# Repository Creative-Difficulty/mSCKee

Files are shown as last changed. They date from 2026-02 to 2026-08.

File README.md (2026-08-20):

# mSCKee



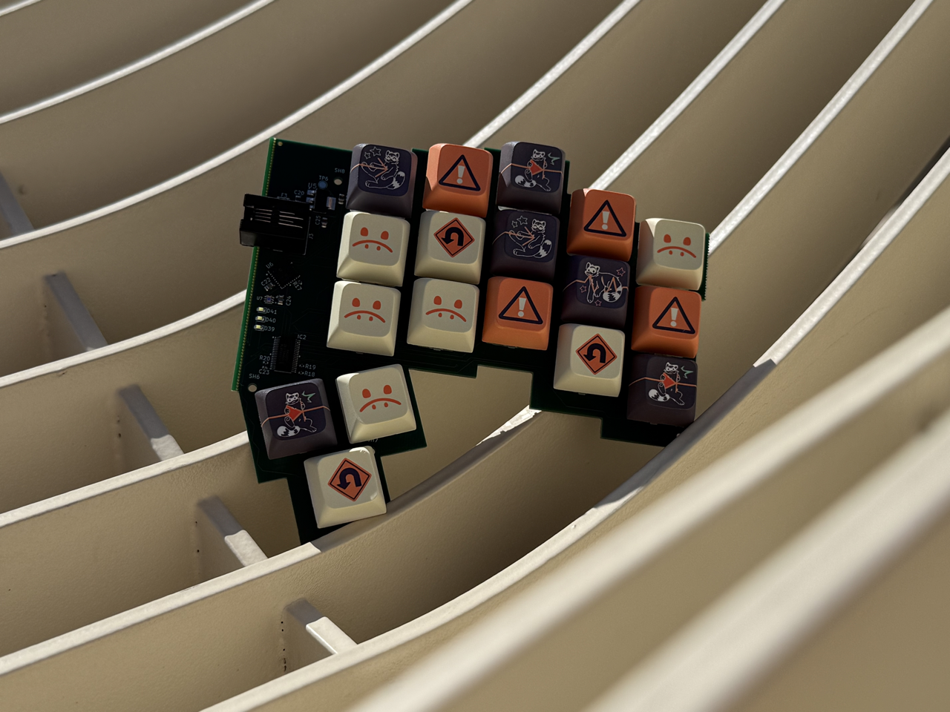
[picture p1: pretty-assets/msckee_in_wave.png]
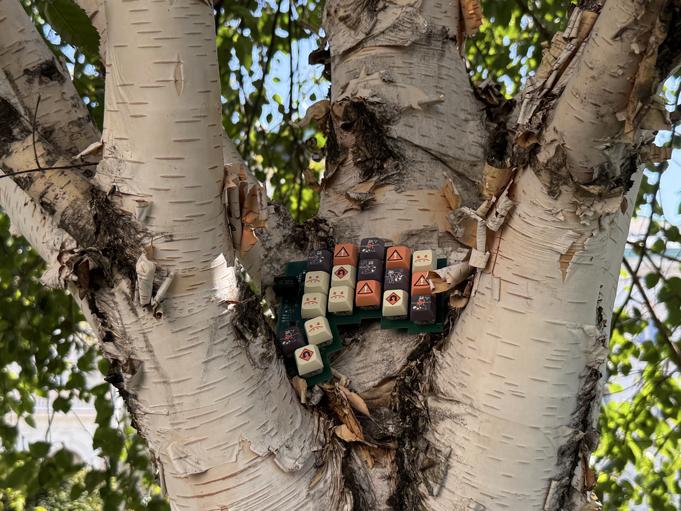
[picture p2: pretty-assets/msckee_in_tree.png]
| | |
|-|-|

__msCKee__ is an open source split Keyboard with per-key white backlighting, and two light sensors, adapting to ambient brightness.

It features:
- dimmable white backlighting for every key, programmable to display animations
- two light sensors (one per side) to automatically dim backlight
- Integrated RP2040 MCU IC
- Minimalist aluminium enclosure
- USB-C 2.0 connectivity
- 4 layer board: Signal - GND - 3,3V and 5V split pour - Signal
- RJ9 cable connection between halves
- Cherry MX 5 pin switch compatible

All manufacturing and part costs were covered by Hack Club through their Outpost program (<https://outpost.hackclub.com>), which I am very grateful for.

Keycaps are custom from Hack Club for Outpost, product photos (top of the README) were taken in Vienna, Austria.

## BOM

The JLC BOM covers the majority of expenses:
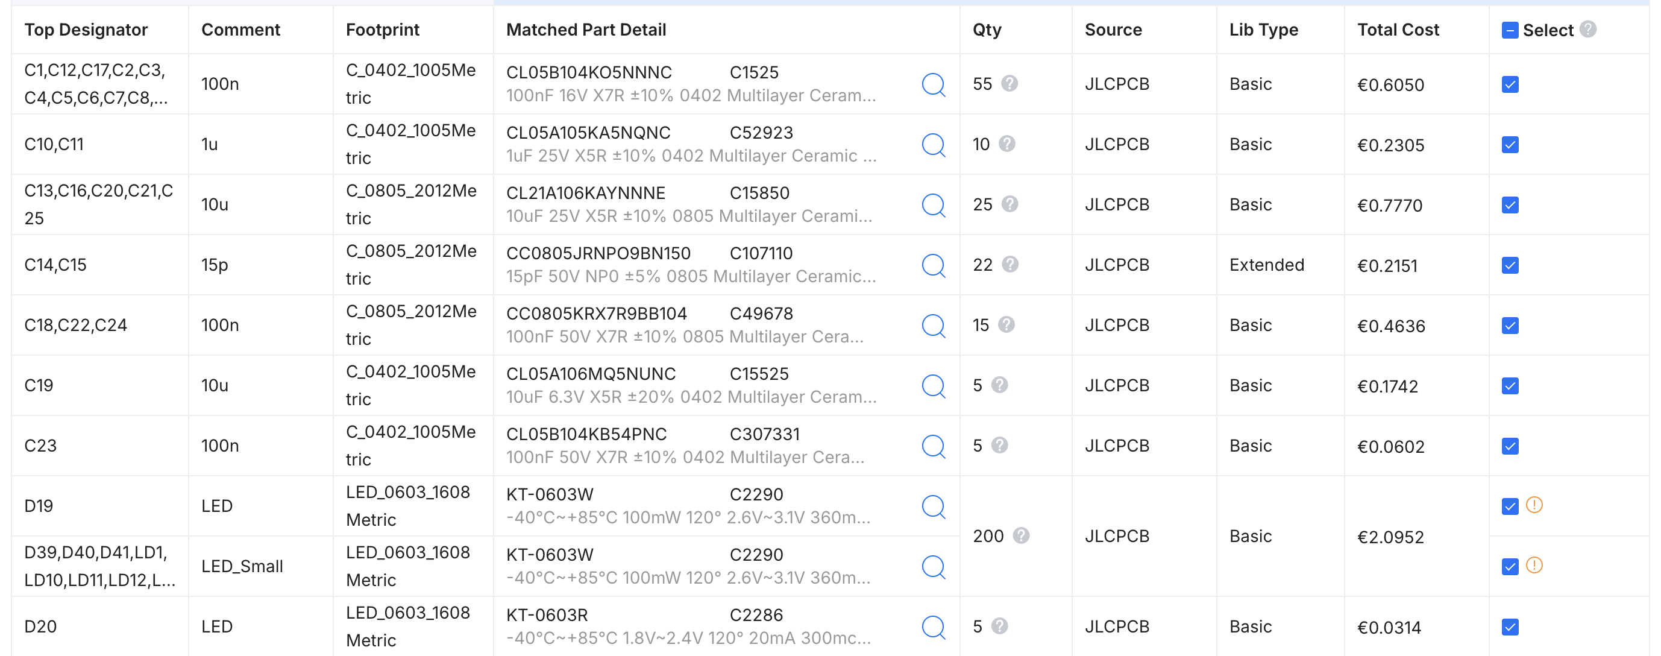
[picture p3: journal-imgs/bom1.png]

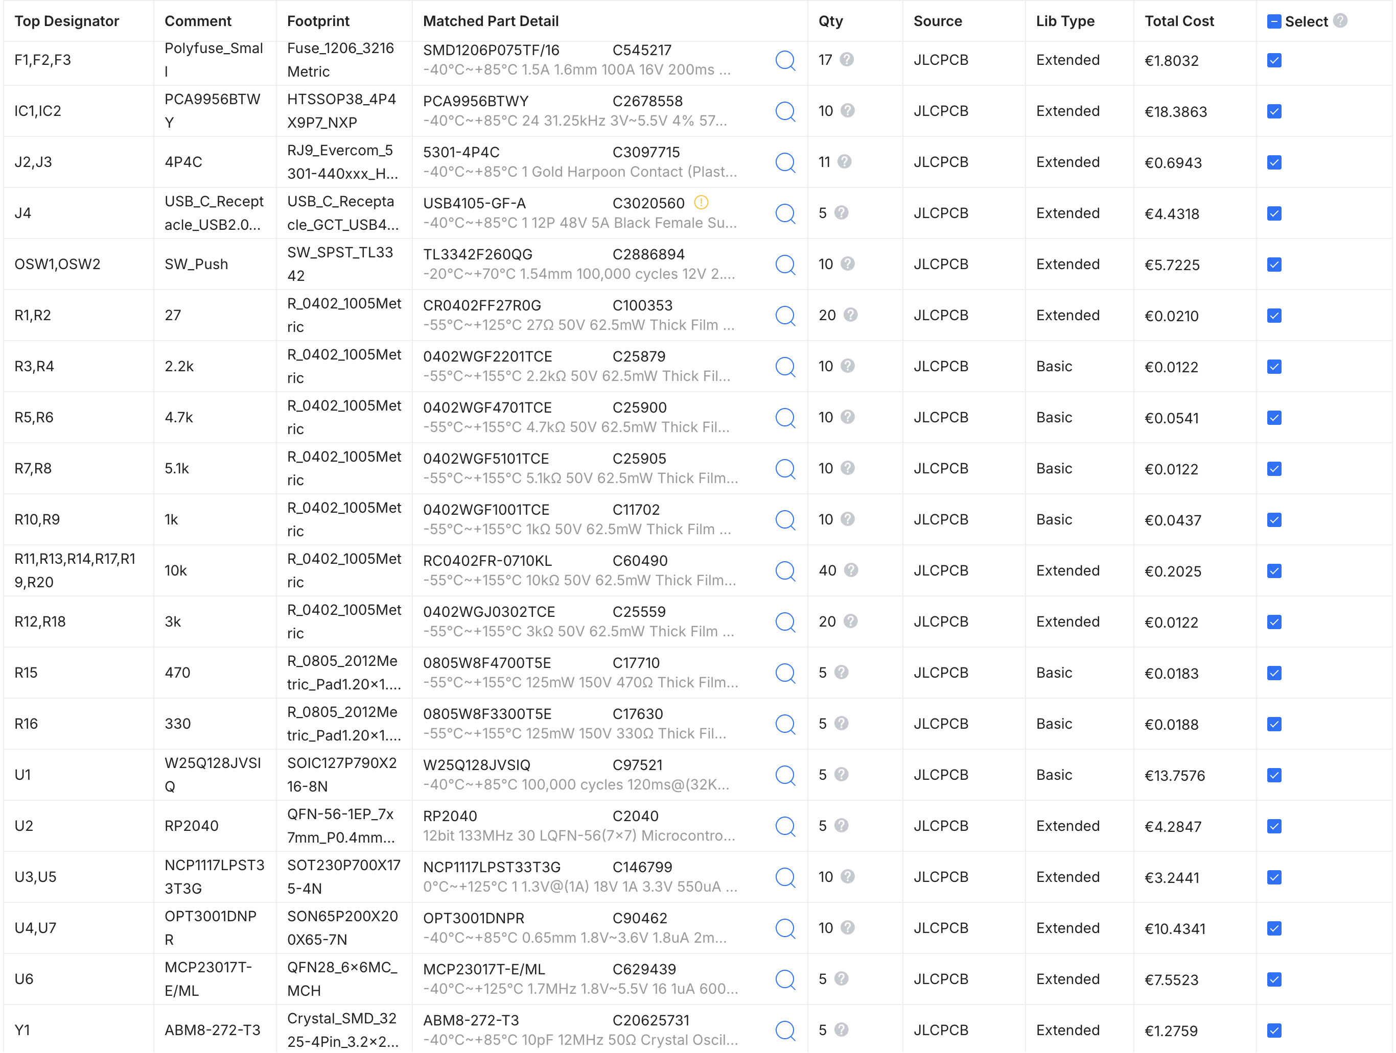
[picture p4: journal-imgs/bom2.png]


Total cost of JLCPCB(A):
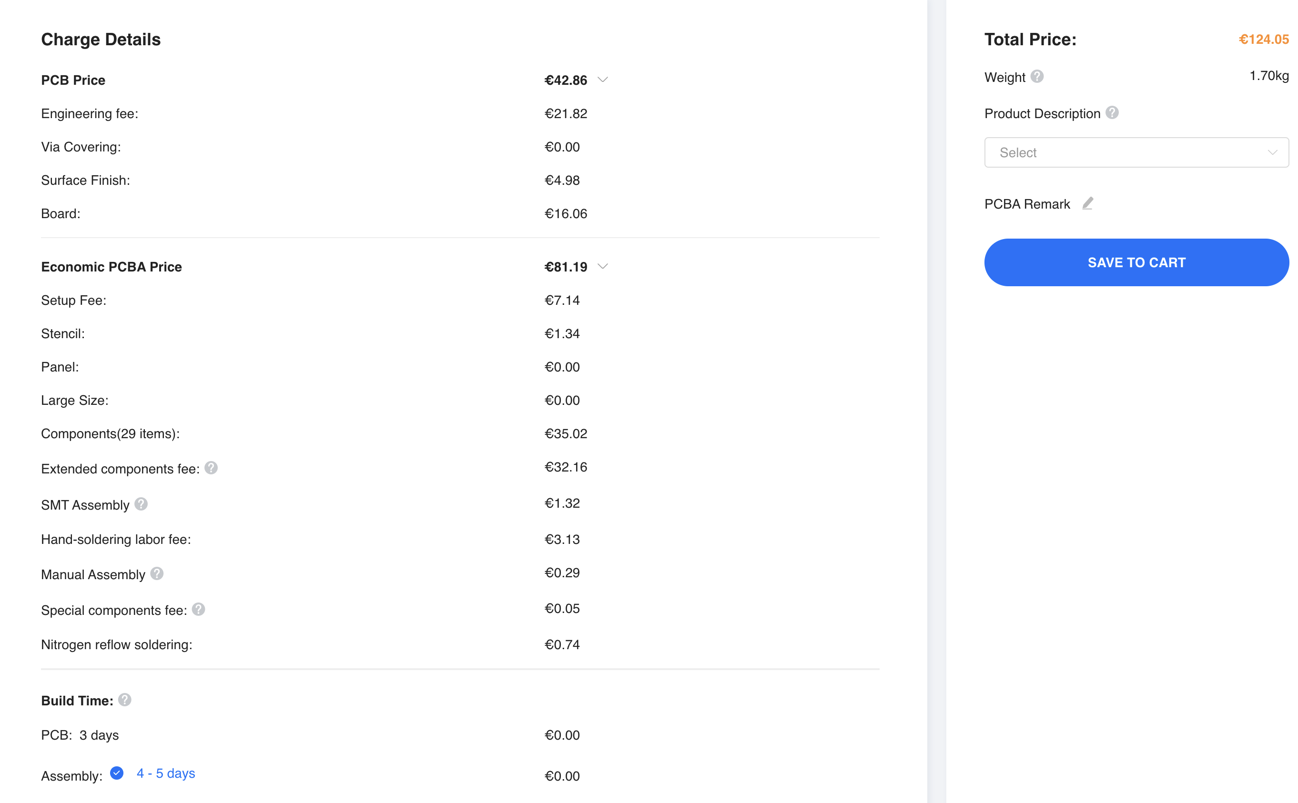
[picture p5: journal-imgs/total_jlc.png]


| Description | Price/Piece | Total Price | Purchase link | Justification |
|---|---|---|---|---|
| JLCPCB manufacturing and PCB assembly | 124.05€ + 22.72€ shipping | 146.77€ | | |
| Cherry MX Red Switch kit | 17.99€ + 11.99€ shipping | 29.98€ | https://shop.cherry.de/cherry-mx2a-rgb-red-switch-kit.html | |
| SP3T Switch: PCM13SMTR | 0.82€ | 5×0.82€ + 5.90€ shipping + 20% VAT = 12€ | https://www.tme.eu/at/details/pcm13smtr/schiebeschalter/c-k/ | No equivalent SP3T switch is available at JLC |
| 1N4148W7F DII SOD-123 diode | 0.05€ | 36×0.05€ + 6.95€ shipping + 20% VAT = 10.5€ | https://www.reichelt.com/at/en/shop/product/small-signal_switching_diode_100_v_300_ma_sod-123-219381 | Diodes for key matrix, mounted on back side of PCB, so not assembled or provided by JLC |
| **Total** | | **199.25€** | | |
| **Total (USD)** | | **232.59USD** | | |

## PCB & schematic images
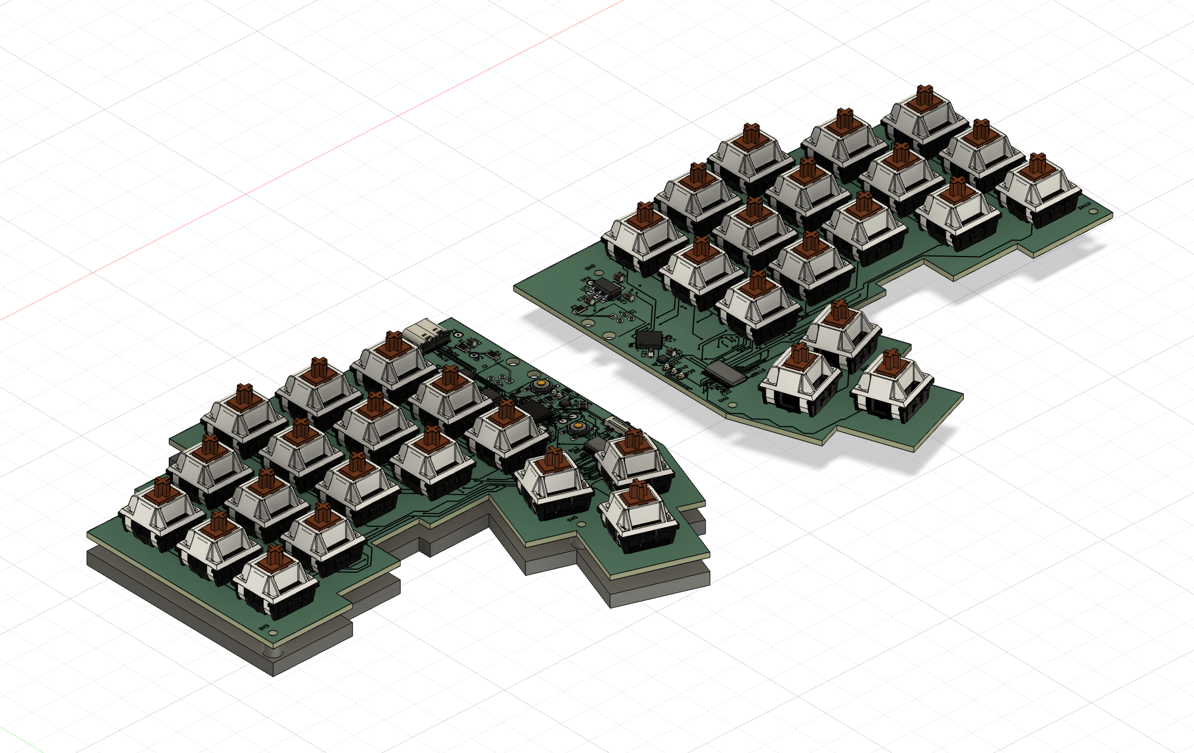
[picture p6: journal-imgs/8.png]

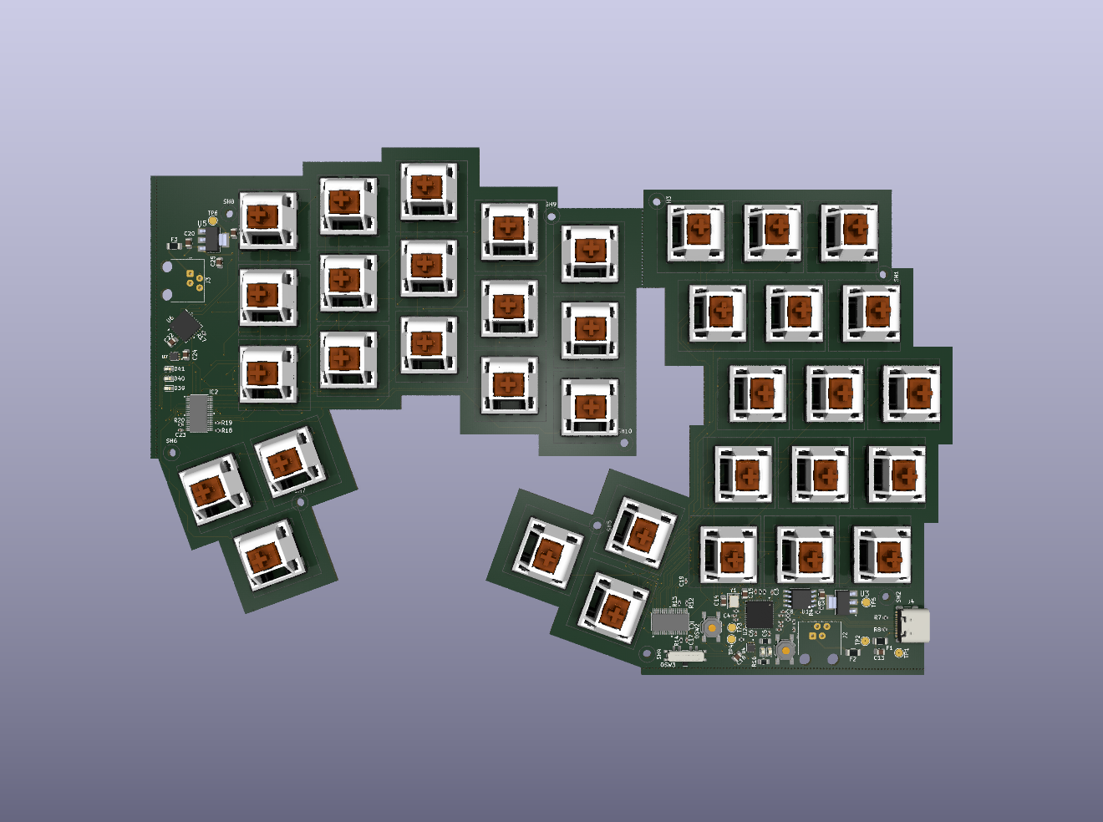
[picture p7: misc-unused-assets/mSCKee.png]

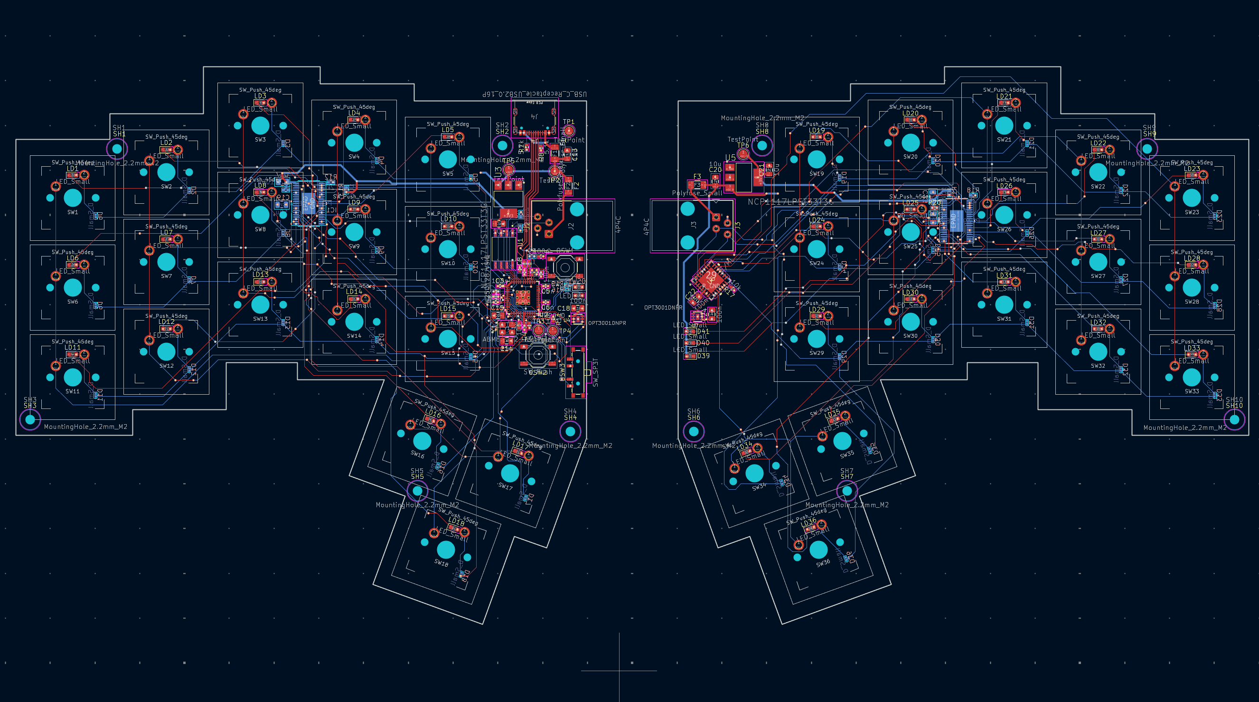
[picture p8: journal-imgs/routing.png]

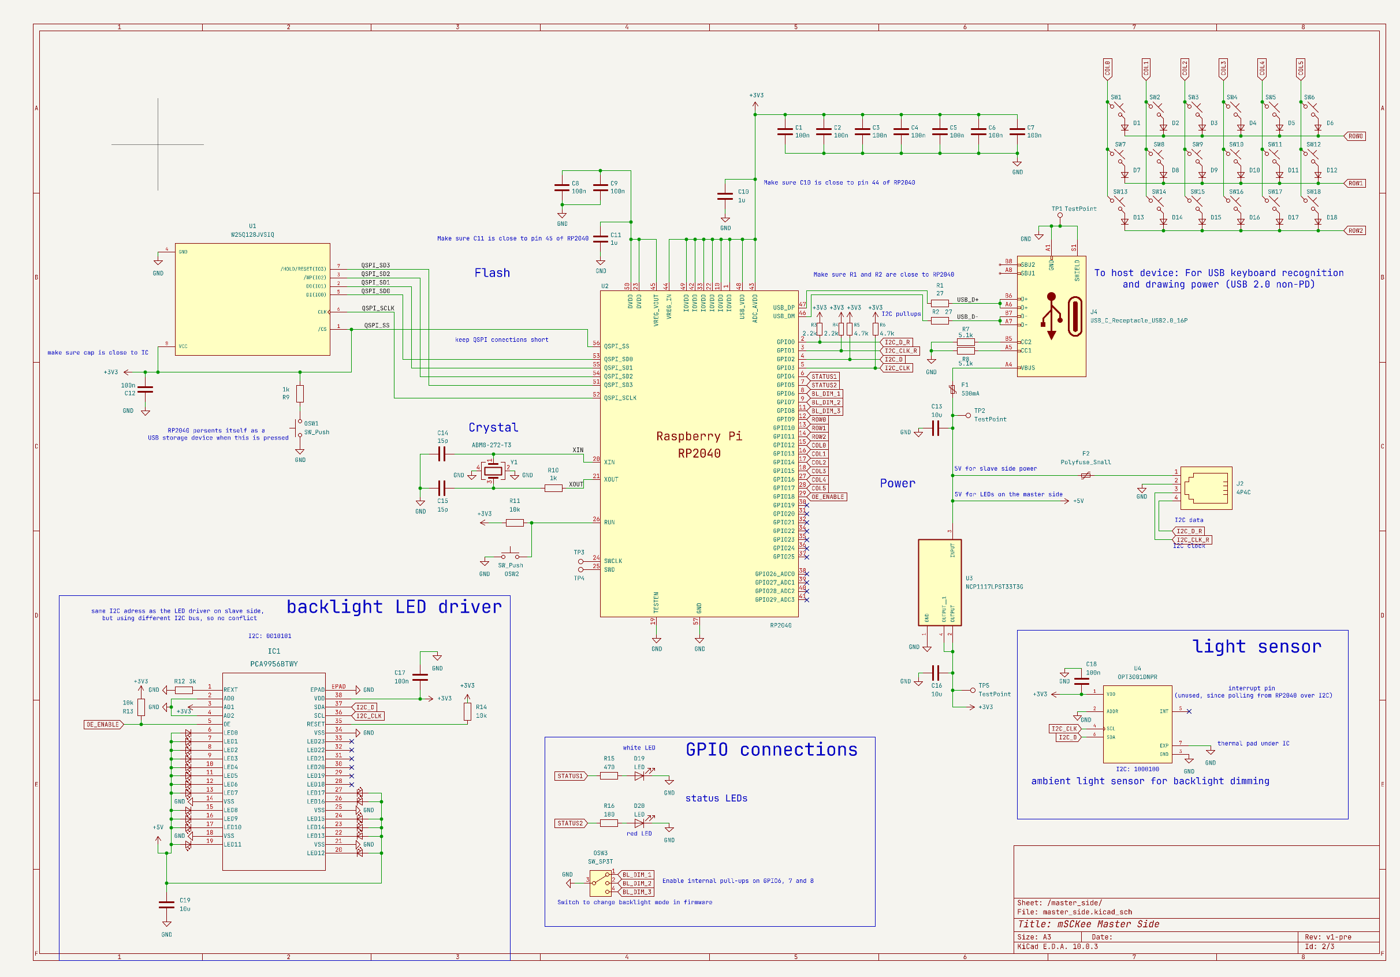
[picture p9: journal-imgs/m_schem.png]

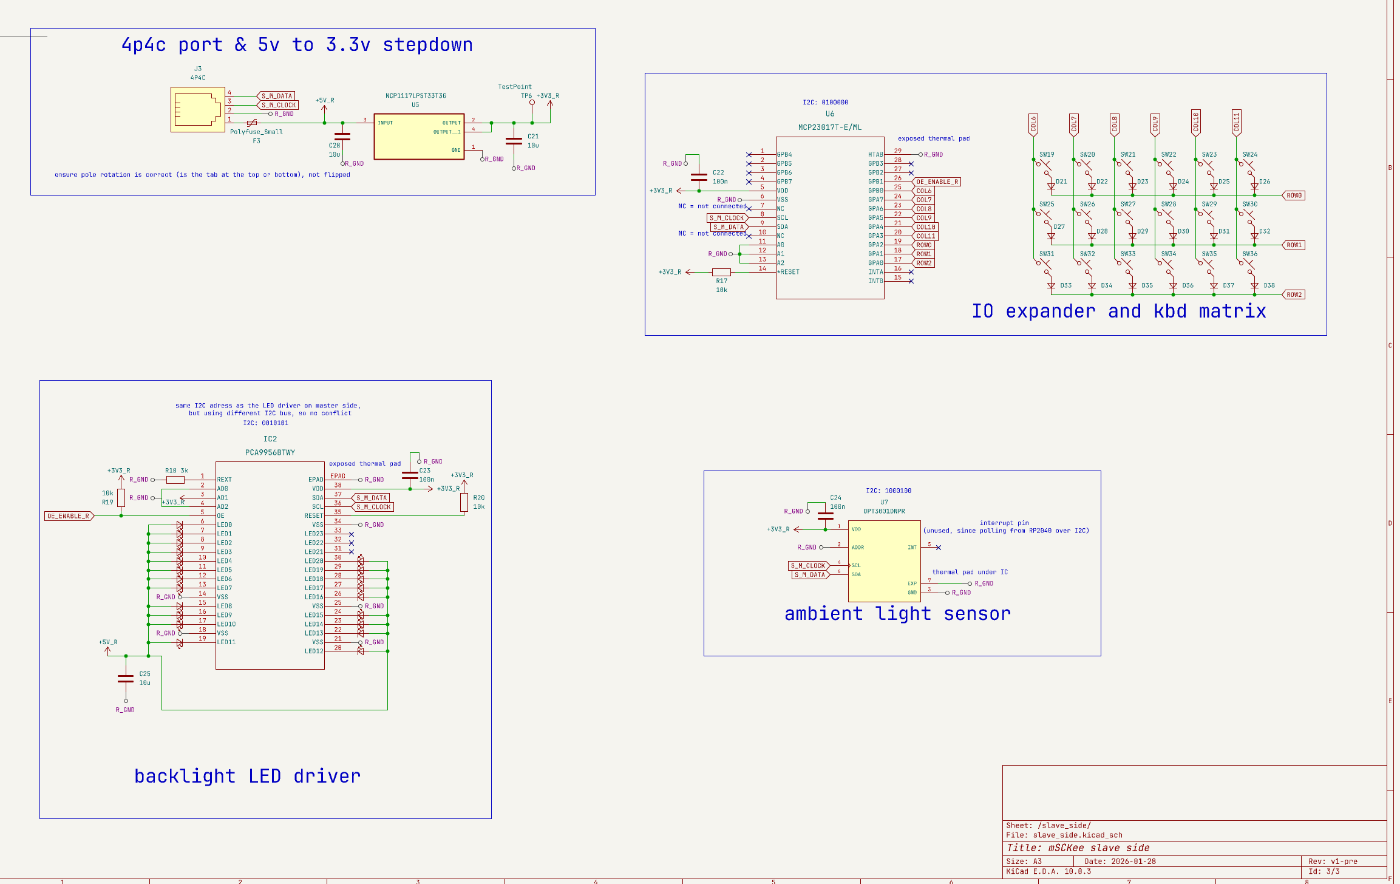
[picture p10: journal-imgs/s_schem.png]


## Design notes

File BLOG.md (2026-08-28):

The PCB arrived, and it worked perfectly, except - It didn't. The RP2040 booted up perfectly but as soon as I tried to flash a test firmware, the board (used as a storage device) ejected itself from Finder. 
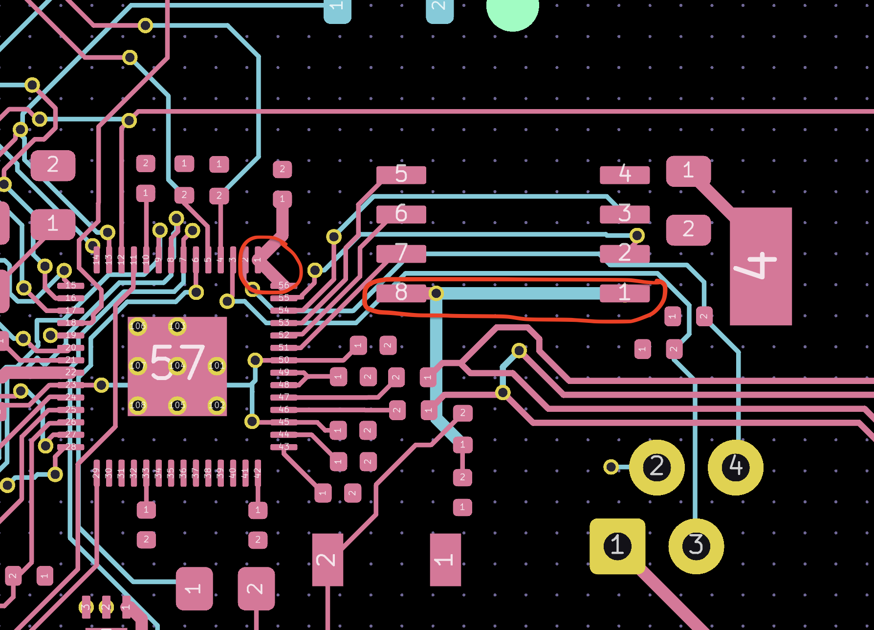
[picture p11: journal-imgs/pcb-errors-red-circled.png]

After some continuity testing with a multimeter, I discovered that I had connected the QSPI CS (chip select) pin of the RP2040 (Pin 56) to the IOVDD pin (Pin 1, a 3,3V input pin powering the RP2040's GPIO pins) and the CS pin (Pin 1) of the WS25Q128 storage chip to the 3,3V net by connecting it to pin 8 of the same chip, which was tied to 3,3V.
This made the storage chip unusable as the chip select pin doesn't ever select or deselect the chip.
KiCad's ratsnet previously led me to believe I had to connect these two (by displaying "+3V3" on them), and while I rembered this quirk when beginning to layout and route the board, a couple weeks later, by the time I ordered the board, I forgot it, and didn't double check with the datasheet one last time.

Due to me not having a hot air station at home, I went to a hackspace in Vienna ([Metalab](https://metalab.at/) in the first district, you should check it out!!) to try and fix the board.

First I desoldered the RP2040:
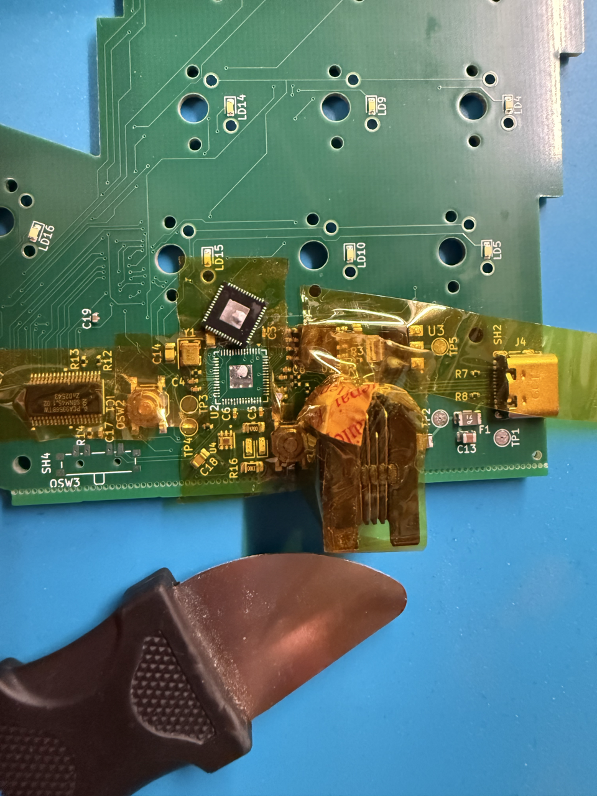
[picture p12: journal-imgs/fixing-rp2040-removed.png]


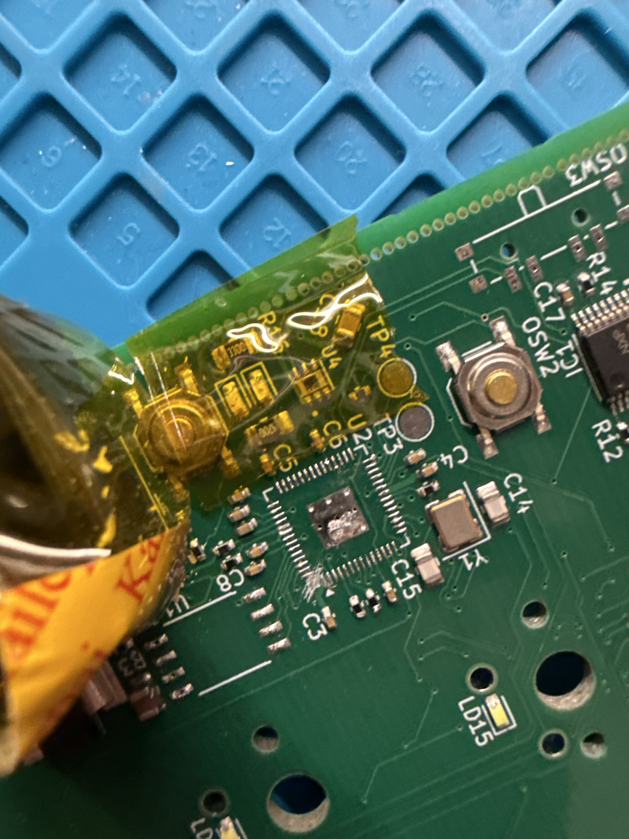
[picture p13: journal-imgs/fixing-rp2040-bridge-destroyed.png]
And broke the connection between pin 56 and pin 1 by scratching it up with a knife: 

I also broke the connection between the storage chip's pin 1 and pin 8 to isolate that pin.

As I've never used a hot air station before, I may have broken the RP2040 and/or W25Q128 storage chip by using too much heat for too long.

I don't have solder paste, flux or a stencil for the RP2040, and I am not confident that I am able to resolder it correctly (RP2040 has a pin pitch of 0.4mm).

While desoldering the storage chip, I unfortunately broke off one of its leads, so I'll have to find a replacement for it.

The best option I know of is reordering the board, which costs 207$. If I manage to resolder the RP2040, I can likely do the repair for a lot cheaper.
I have a second untouched assembled PCB from JLC, and I will try to fix that before reordering.

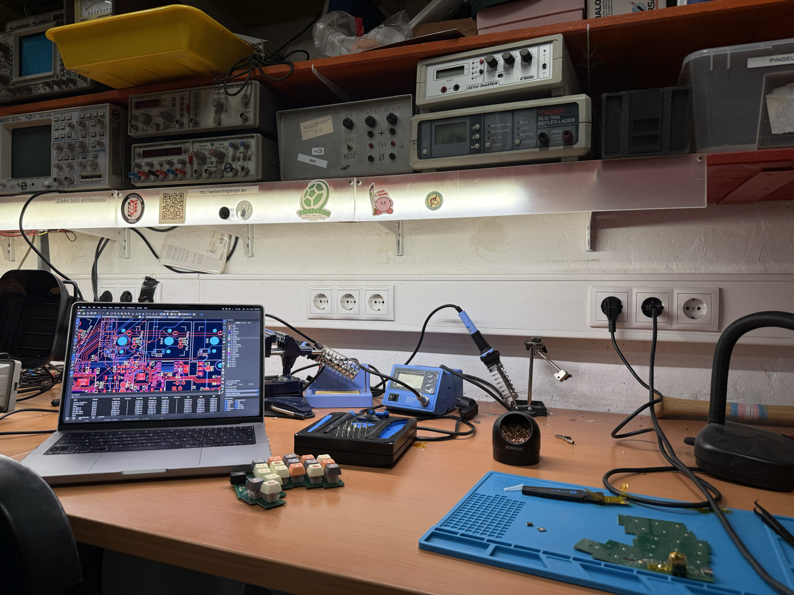
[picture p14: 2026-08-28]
journal-imgs/fixing-overview.png

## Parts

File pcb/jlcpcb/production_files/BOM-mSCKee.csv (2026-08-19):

Comment | Designator | Footprint | LCSC | Quantity
100n | C1,C12,C17,C2,C3,C4,C5,C6,C7,C8,C9 | C_0402_1005Metric | C1525 | 11
100n | C23 | C_0402_1005Metric | C307331 | 1
100n | C18,C22,C24 | C_0805_2012Metric | C49678 | 3
10k | R11,R13,R14,R17,R19,R20 | R_0402_1005Metric | C60490 | 6
10u | C19 | C_0402_1005Metric | C15525 | 1
10u | C13,C16,C20,C21,C25 | C_0805_2012Metric | C15850 | 5
15p | C14,C15 | C_0805_2012Metric | C107110 | 2
1k | R10,R9 | R_0402_1005Metric | C11702 | 2
1u | C10,C11 | C_0402_1005Metric | C52923 | 2
2.2k | R3,R4 | R_0402_1005Metric | C25879 | 2
27 | R1,R2 | R_0402_1005Metric | C100353 | 2
330 | R16 | R_0805_2012Metric_Pad1.20x1.40mm_HandSolder | C17630 | 1
3k | R12,R18 | R_0402_1005Metric | C100635 | 2
4.7k | R5,R6 | R_0402_1005Metric | C105871 | 2
470 | R15 | R_0805_2012Metric_Pad1.20x1.40mm_HandSolder | C17710 | 1
4P4C | J2,J3 | RJ9_Evercom_5301-440xxx_Horizontal | C3097715 | 2
5.1k | R7,R8 | R_0402_1005Metric | C25905 | 2
ABM8-272-T3 | Y1 | Crystal_SMD_3225-4Pin_3.2x2.5mm | C20625731 | 1
D_Small | D1,D10,D11,D12,D13,D14,D15,D16,D17,D18,D2,D21,D22,D23,D24,D25,D26,D27,D28,D29,D3,D30,D31,D32,D33,D34,D35,D36,D37,D38,D4,D5,D6,D7,D8,D9 | D_SOD-123 | C81598 | 36
LED | D20 | LED_0603_1608Metric | C2286 | 1
LED | D19 | LED_0603_1608Metric | C2290 | 1
LED_Small | D39,D40,D41,LD1,LD10,LD11,LD12,LD13,LD14,LD15,LD16,LD17,LD18,LD19,LD2,LD20,LD21,LD22,LD23,LD24,LD25,LD26,LD27,LD28,LD29,LD3,LD30,LD31,LD32,LD33,LD34,LD35,LD36,LD4,LD5,LD6,LD7,LD8,LD9 | LED_0603_1608Metric | C2290 | 39
MCP23017T-E/ML | U6 | QFN28_6x6MC_MCH | C629439 | 1
NCP1117LPST33T3G | U3,U5 | SOT230P700X175-4N | C146799 | 2
OPT3001DNPR | U4,U7 | SON65P200X200X65-7N | C90462 | 2
PCA9956BTWY | IC1,IC2 | HTSSOP38_4P4X9P7_NXP | C2678558 | 2
Polyfuse_Small | F1,F2,F3 | Fuse_1206_3216Metric | C545217 | 3
RP2040 | U2 | QFN-56-1EP_7x7mm_P0.4mm_EP3.2x3.2mm | C2040 | 1
SW_Push | OSW1,OSW2 | SW_SPST_TL3342 | C2886898 | 2
USB_C_Receptacle_USB2.0_16P | J4 | USB_C_Receptacle_GCT_USB4105-xx-A_16P_TopMnt_Horizontal | C3020560 | 1
W25Q128JVSIQ | U1 | SOIC127P790X216-8N | C97521 | 1
TestPoint | TP5 | TestPoint_Pad_D2.0mm |  | 1
TestPoint | TP4 | TestPoint_Pad_D2.0mm |  | 1
TestPoint | TP3 | TestPoint_Pad_D2.0mm |  | 1
TestPoint | TP1 | TestPoint_Pad_D2.0mm |  | 1
TestPoint | TP2 | TestPoint_Pad_D2.0mm |  | 1
TestPoint | TP6 | TestPoint_Pad_D2.0mm |  | 1

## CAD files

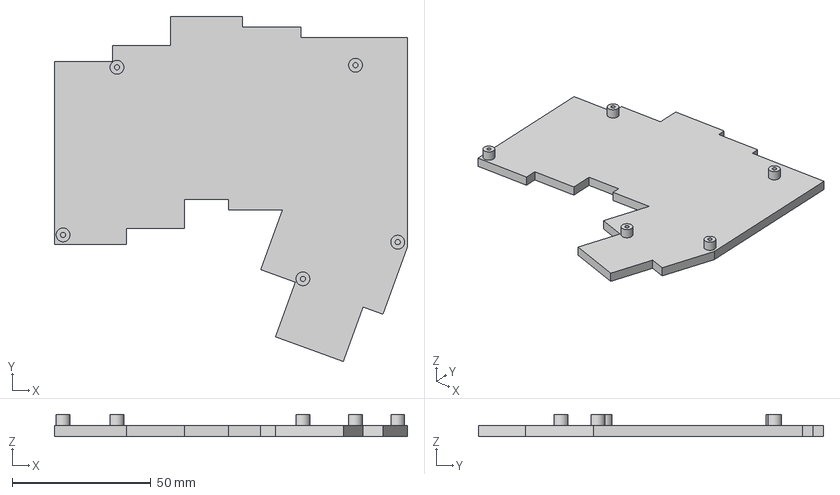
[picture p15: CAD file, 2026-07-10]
cad/minimal Case.step
127.5 x 124.4 x 8.00 mm

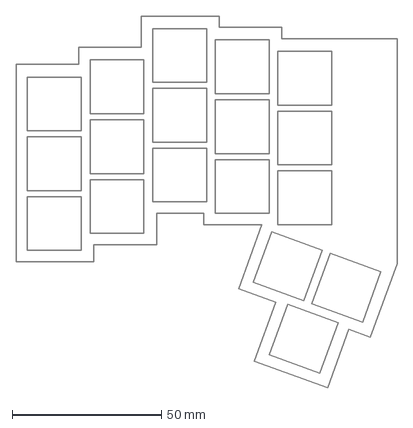
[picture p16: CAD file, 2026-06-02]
outline_and_keys.dxf
127.5 x 124.4 mm

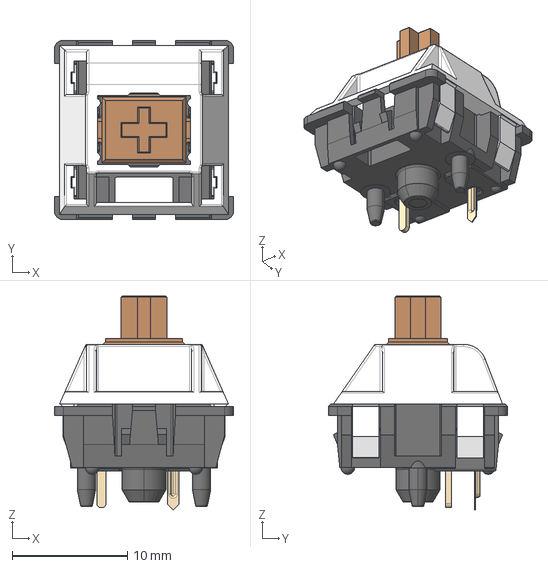
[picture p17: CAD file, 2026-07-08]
pcb/pcb-lib/ai03-MX_V2/kiswitch-SW_Cherry_MX_PCB.stp
15.6 x 15.6 x 18.6 mm

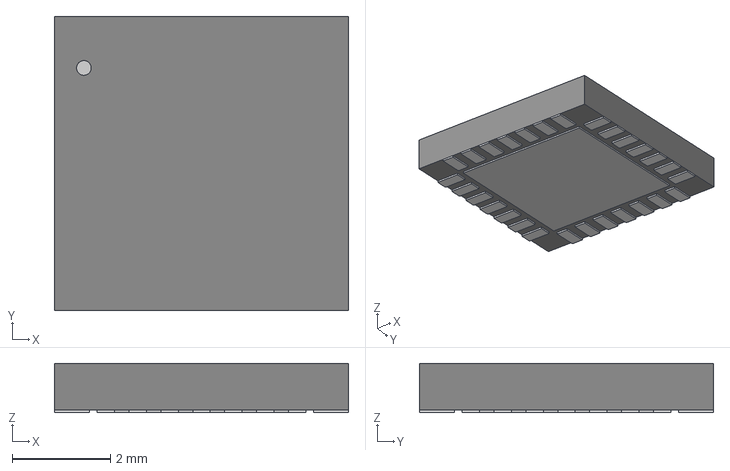
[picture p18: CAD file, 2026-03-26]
pcb/pcb-lib/MCP23017T_E_ML/QFN28_6x6MC_MCH.step
6.00 x 6.00 x 1.00 mm

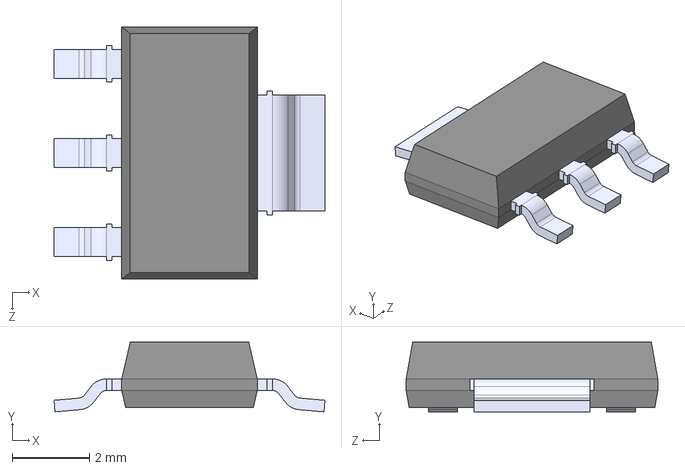
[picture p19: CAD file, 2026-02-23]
pcb/pcb-lib/NCP1117LPST33T3G/NCP1117LPST33T3G.step
7.00 x 1.80 x 6.50 mm

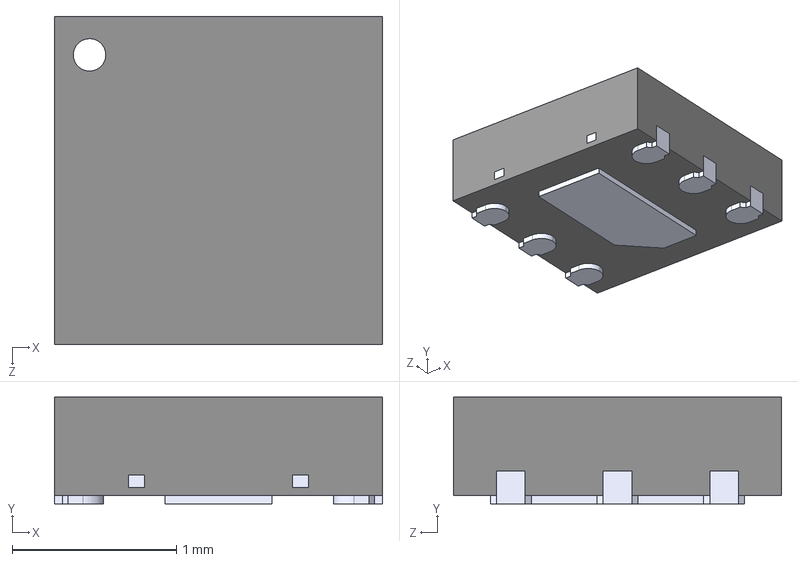
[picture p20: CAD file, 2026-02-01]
pcb/pcb-lib/OPT3001DNPR/OPT3001DNPR.step
2.00 x 0.65 x 2.00 mm

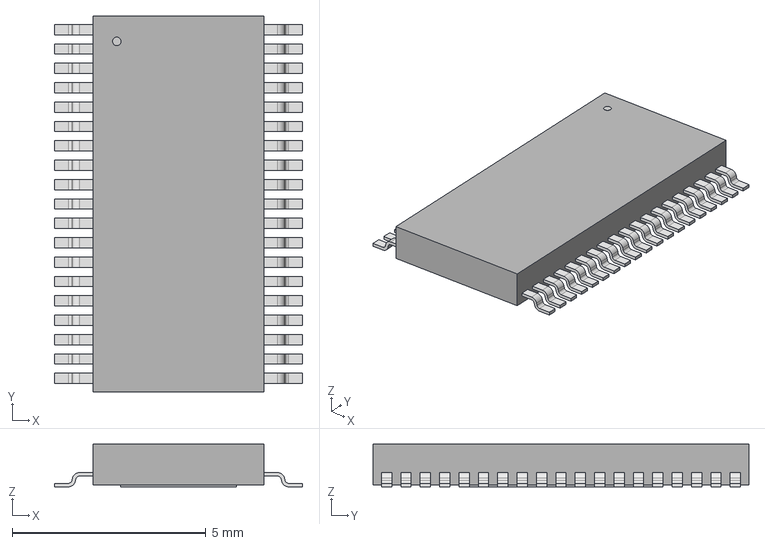
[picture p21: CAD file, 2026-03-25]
pcb/pcb-lib/PCA9956BTWY/HTSSOP38_4P4X9P7_NXP.step
6.40 x 9.70 x 1.10 mm

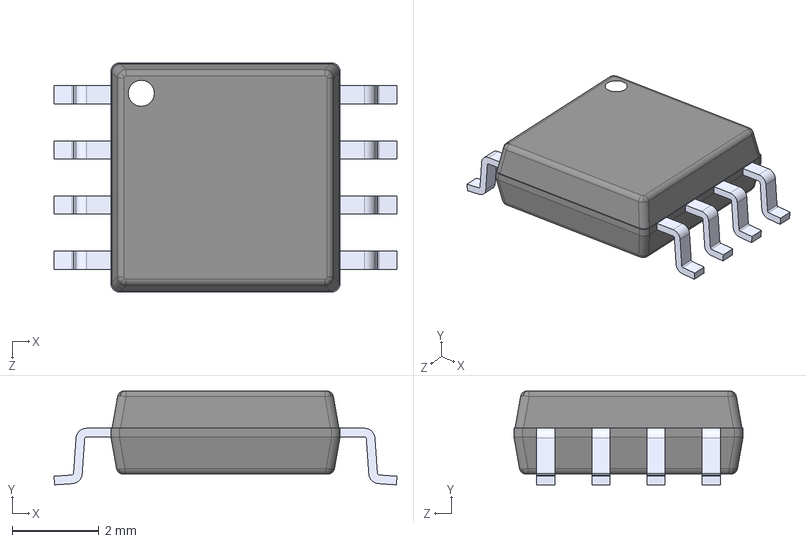
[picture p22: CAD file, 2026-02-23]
pcb/pcb-lib/W25Q128JVSIQ/W25Q128JVSIQ.step
7.90 x 2.16 x 5.28 mm

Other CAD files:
misc-unused-assets/minimal Case.step
Outline and keys.dxf
cad/minimal Case.f3z
misc-unused-assets/minimal Case.f3z

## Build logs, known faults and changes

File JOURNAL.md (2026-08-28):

# Split Keyboard with per-key backlighting — Journal 

## Entry 1: 1 hour

- ID: 16105
- Author: Alex
- Created At: 2025-10-31T22:29:00Z

### Content

My first journal entry for my first hardware project :)

# Rough Scope / Requirements

The first iteration of the keyboard will only be a modification of the one in the guide, as I'm still a beginner at KiCad, electronics and PCB design. These are the main differences between this board and the guide:

- RP2040 instead of nRF microcontroller
- Neopixels or similar LEDs under every key
- Only one chip will be used for both sides (master slave concept)
- Connectivity: Just USB-C, so no battery will be used
- In future iterations: The ability to attach a variety of (magnetic?) modules to the side of the keyboard  with:
  - Rotary encoders (e.g. volume dial)
  - push buttons (e.g. hotswappable additional keys, but also normal buttons)
  - toggle switches (could be used for simracing or flight simmming)
  - etc (to be determined)

# Component selection

- Main (Master) Microcontroller: likely RP2040
- Slave: I2C expander or parallel-in shift register which sends data to Master
- For data transmission between master (left side) and slave (right side): Likely TRRS if the bandwidth is sufficient

# First concept design

Bildschirmfoto 2025-10-31 um 23.16.49

## Entry 2: 15 hours

- ID: 16106
- Author: Alex
- Created At: 2026-01-31T14:52:00Z

### Content

Since the last journal, I've spent a bunch of time researching, learning electronics fundamentals and redesigning the basic RP2040 circuit (USB-C, flash, clock) over and over again.

I spent 5 hours researching electronics, component selections, PCB design and routing. Great Scott on youtube does a great (hehe) job of explaining the fundamental components, for higher level (concepts like I2C and SPI), Altium Academy has some great videos. I also read through The RP2040 hardware design guide (<https://pip-assets.raspberrypi.com/categories/814-rp2040/documents/RP-008279-DS-1-hardware-design-with-rp2040.pdf>) and used it as a reference in addition to the RP2040 datasheet.

After getting a grasp on the basics, I started designing the circuit schema in KiCad, starting with the left side of the split. I took the recommended minimal RP2040 circuit from the hardware design guide, then I replaced microUSB with a type C connector (more modern, better compatibility) and messed around with the layout of the traces connecting the MCU to the flash until I found a better layout (the flash reset button wiring in the hardware design guide is very confusing in my opinion). I also landed on splitting off a power rail to the other side of the keyboard (just branching out a trace before the buck converter (ncp1117) and feeding it directly into a TRRS receptacle), after spending about half an hour researching and realizing there is no better solution. In total this also took about 5 hours.

The power-related stuff on the left side of the split:
Bildschirmfoto 2026-06-01 um 00.57.57

Then I added status LEDs, the TRRS receptacle to connect the two halves, an ambient light sensor for automatic backlight dimming (TI OPT3001), a rotary encoder as a volume knob, and a button to switch between backlight dimming modes. I used the datasheets of the components as a reference (ctrl+f was my best friend). Initially, I was drawn to using a switch for selecting backlighting modes, however after descending into the madness that are different types of switches and wiring, I decided to opt for the simpler solution of just using a push button. This took about 5 hours in total since I wasn't familiar with the components (especially the light sensor).

GPIO connections on the left side (TRRS not pictured here, but on above screenshot with other power-related components):
Bildschirmfoto 2026-06-01 um 01.01.15

Next things to do are: keyboard matrix, backlighting, and figuring out how to avoid shorting the various poles of the TRRS cable together when plugging/unplugging it while powered.

Current screenshot of the entire schematic for the "master" side (left):
Bildschirmfoto 2026-01-31 um 15.36.46

## Entry 3: 2 hours

- ID: 16107
- Author: Alex
- Created At: 2026-02-23T22:22:00Z

### Content

I took my time deciding on the layout and format as I plan to daily drive this board in the future and learn a new layout with it (colemak DH). I found an awesome program called QCAD/CAM, with which I tweaked the outline generated by ergogen (a good tutorial on outlines in ergogen: <https://flatfootfox.com/ergogen-part2-outlines/>) to make it more aesthetically pleasing and ergonomic. Overall the visual design is done, however I haven't gotten around to finishing the cicuit design yet.

The finished outline with keys shown:
Bildschirmfoto 2026-02-23 um 23.10.36

Intial outline from ergogen:
Bildschirmfoto 2026-02-23 um 23.19.25

## Entry 4: 8 hours

- ID: 16108
- Author: Alex
- Created At: 2026-06-02T02:41:00Z

### Content

I decided to replace the TRRS connector between the two halves with RJ45 to mitigate the issue of shorting together some connections when (un)plugging TRRS while its powered.Bildschirmfoto 2026-06-02 um 04.18.02

Then I made the schematic of the 3x6 key matrix. On keyboard specific KiCAD stuff, I watched some tutorials by Joe Scotto (I think his videos are recommended in the macropad guide too).
Bildschirmfoto 2026-06-02 um 04.25.52

I also replaced some default symbols with proper ones ([snapmagic](https://www.snapeda.com/) is a good website for finding symbols, footprints and 3d models) and added a push button to the RUN pin to make it functional. I added the LED driver and LEDs (not in a matrix, the LED driver has 24 pins!) to the schematic, and compartmentalized the schematic to make it more readable.
Bildschirmfoto 2026-06-02 um 04.25.35

Everything up to here took about 3 hours.

Current master (left) side schematic:
Bildschirmfoto 2026-06-02 um 04.26.56

Because the two halves of my split are not mirrored versions of eachother, I created a new hierarchical sheet for the right side. I learned that KiCad connects identically named nets on different sheets together, which led to having to create custom nets for GND (R_GND), +3V3 (+3V3_R) and +5V (+5V_R) and making sure not to use the defaults, which was pretty annoying. After I had that set up, I added the otehr side of the RJ45 connector, also with an NCP1117 stepdown to 3,3v.
Bildschirmfoto 2026-06-02 um 04.33.24

Then I added the IO expander and copied the keyboard matrix over from the master side.
Bildschirmfoto 2026-06-02 um 04.34.10

Same with the LED driver:
Bildschirmfoto 2026-06-02 um 04.35.01

And the ambient light sensor:
Bildschirmfoto 2026-06-02 um 04.35.18

I decided to route all data between the two sides over I2C, so I could use an RJ45 connector with 4P4C (4 connections in the cable), one for ground, one for I2C data, one for I2C clock, and one for 5V power. Bildschirmfoto 2026-06-02 um 04.38.37

Creating the second side of the PCB schematic took 5 hours.
Complete right side of the schematic:
Bildschirmfoto 2026-06-02 um 04.40.46

## Entry 5: 3 hours

- ID: 16109
- Author: Alex
- Created At: 2026-06-02T02:59:00Z

### Content

Got the kbplacer plugin set up in KiCad and imported and converted the ergogen exported files to use them with it. Messed up here multiple times, so this was probably the most frustrating part. I know using autoplacing is a grey area in whats allowed, however placing 36 keys exactly at these spacings and weird angles is impossible manually. Imported the DXF file which I modified from the exported ergogen outline into KiCad and tried to align it perfectly with where kbplacer is placing the keys (still working on that!).

Bildschirmfoto 2026-06-02 um 04.48.44

I noticed that the topmost line of the outline of the keyboard was angled slightly, which messed up all of my exact placings, so I'll have to redo that in QCADCAM (that software is awesome btw).

Also KiCad does not like the imported DXF, as the outline does not get displayed correctly in the 3D editor (and there are 400+ DRC errors lol). kbplacer is giving me a bunch of errors too (but it works lol), so there's a lot left to clean up (yes I know the component placements are terrible, I'll move them once I have the outline and kbplacer stuff figured out)!

## Entry 6: 1 hour

- ID: 16110
- Author: Alex
- Created At: 2026-06-02T20:54:00Z

### Content

Bildschirmfoto 2026-06-02 um 22.51.32
I noticed that the space I allocated for all the components on the layout was way too small, so I went back into CAD and modified the outline to give the components more space. Then I started re-layouting the components, starting from the USB-C port.

---Journals from this point on are from fallout---

## Entry 7: 2 hours 9 minutes (lapse)

- ID: 11626
- Author: Alex
- Created At: 2026-06-04T15:23:08Z

### Content

I redid the USB traces & got confused while routing the RP2040 and its decoupling caps.

I also had to do some research (reddit (r/KiCad), raspi forums, official hardware design guide are the main resources I used), I had to look up a lot of things as I went, as this is my first hardware project.

Lots of TODOs:

- Fix 0402 imperial and metric confusion
- Fix DRC errors (are holes of claws of USB-C and ethernet receptacles big enough to manufacture at JLC?)
- Proper decoupling cap distribution between pins
- Manage the +1.1V and +3.3V situation (maybe create +1.1V net)
- Likely more stuff I forgot

Screenshot of the PCB region I worked on here:
Bildschirmfoto 2026-06-04 um 17.13.26.png

### Recording Links

- <https://lookout.hackclub.com/api/media/cda9790b-99ee-49d6-a44a-27ab50fa6f65/video.mp4>

## Entry 8: 1 hour 11 minutes (lapse)

- ID: 11695
- Author: Alex
- Created At: 2026-06-04T19:55:05Z

### Content

I tried to understand the decoupling capacitor placement for the RP2040 and realized I did the cap layout all wrong. In the process a made a lil table of all the power pins and a little sketch to illustrate their physical locations on the footprint, and what kind of caps they are supposed have. Please excuse by subpar handwriting skills. (The screen was on the same view for a long time at the end because I was writing this by hand).


### Recording Links

- <https://lookout.hackclub.com/api/media/045bb16c-87d7-4f40-a2ca-23ea957c171d/video.mp4>

## Entry 9: 24 minutes (lapse)

- ID: 11730
- Author: Alex
- Created At: 2026-06-04T21:59:53Z

### Content

I now think I know how to route the decoupling caps of the RP2040 cleanly and the "right way". This is only part 1, I'll be finishing it tomorrow.
Bildschirmfoto 2026-06-04 um 23.59.11.png

### Recording Links

- <https://lookout.hackclub.com/api/media/48901000-90c8-45db-88f3-d2075e02c8be/video.mp4>

## Entry 10: 1 hour 5 minutes (lapse)

- ID: 11810
- Author: Alex
- Created At: 2026-06-05T10:21:52Z

### Content

Today I finished routing the decoupling caps, routed the crystal oscillator and two status LEDs.

I also figured out that I can’t route with this trace width and how to change it. Now I just need to make it apply retroactively to all other traces and redo some routing, because this thinner trace width is much easier to deal with. I already had the constraints setup correctly in the 'constraints' tab, but KiCad still used the minima from the 'Default' netclass, so I had to update those.

Part of the PCB I worked on today:
Bildschirmfoto 2026-06-05 um 12.17.59.png

### Recording Links

- <https://lookout.hackclub.com/api/media/1e5dcf67-8fbf-4721-ad80-1dc5848d90b4/video.mp4>

## Entry 11: 1 hour 15 minutes (lapse)

- ID: 11827
- Author: Alex
- Created At: 2026-06-05T12:36:54Z

### Content

Routed flash storage, timer crystal, reset buttons and test pads. Also I improved the general layout around the RP2040, even though it is still quite messy. Corrected a few mistakes I made before like the default trace width being very wide.

Due to the keyboard switches and their LEDs being laid out by kbplacer from top to bottom, but in the schematic numbered by side (left: 1-18, right: 19-36), there are some mismatches: Many LEDs from the left side want to connect to the LED driver on the right and vice versa, and many switches also connect to the wrong side.

Portion of the PCB i worked on:
Bildschirmfoto 2026-06-05 um 14.29.32.png

### Recording Links

- <https://lookout.hackclub.com/api/media/234d2431-5c4f-45ff-9534-860b33ae7efb/video.mp4>

## Entry 12: 21 minutes (lapse)

- ID: 12135
- Author: Alex
- Created At: 2026-06-06T21:16:25Z

### Content

Renamed all the key switches and diodes (those only on the right side) to fix where the kbplacer auto placement messed up. Also fixed some col/row assignments, because kbplacer also messed up there. The cleanup seems to take more work than if I had just positioned all the switches manually, but hey, I need that exact placement.

Part of the PCB I worked on (the entire thing):Bildschirmfoto 2026-06-06 um 23.12.39.png

### Recording Links

- <https://lookout.hackclub.com/api/media/10a55efe-bd82-4567-8f5d-98837fecc5bf/video.mp4>

## Entry 13: 15 minutes (lapse) + 40 minutes lost by lapse due to going through some tunnels in a train

- ID: 12445
- Author: Alex
- Created At: 2026-06-08T08:00:03Z

### Content

Renaming footprints and pads, fixing nets, fixing silkscreen.

About 40 minutes got lost due to no internet connection, I hope I can get those refunded :( (both the time elapsed in the status bar and in the lookout window were increasing, decreasing and freezing a lot, so unfortunately none of them is reliable).
Bildschirmfoto 2026-06-08 um 09.53.35.png

### Recording Links

- <https://lookout.hackclub.com/api/media/84248ee9-f5a4-41b3-87ac-e47bc816097e/video.mp4>

---Journals from this point on are NOT from fallout---
NOTE: Dates are written as dd.mm.yyyy format from here on.

## Entry 14: 2 hours, 30.06.2026
Routed most of the LEDs to the LED driver on the right side and routed the rest of all unconnected things on the switches, doides ad LEDs on the right half, except the Row/col wiring for the thumb cluster (TODO).
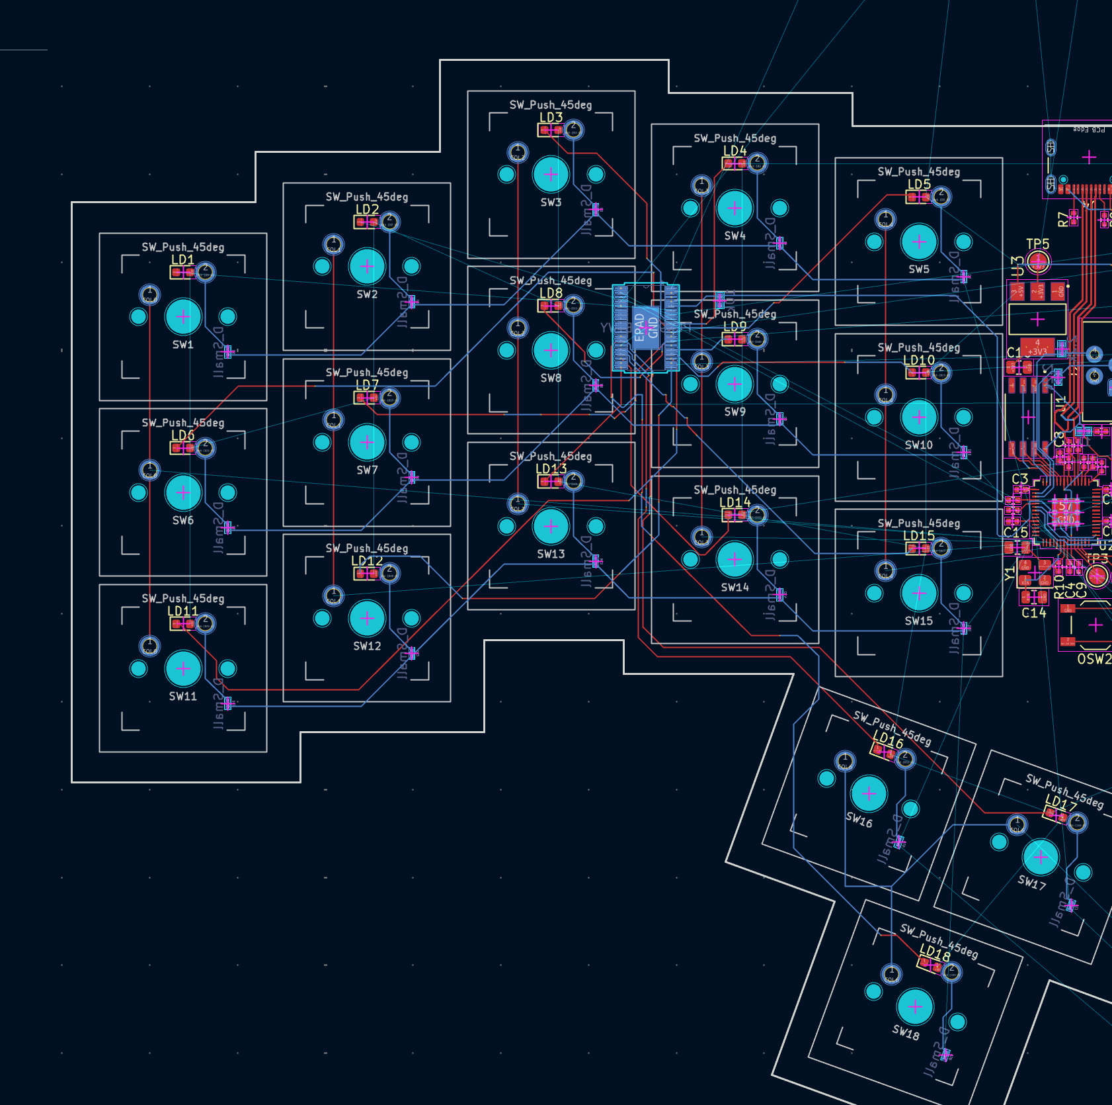
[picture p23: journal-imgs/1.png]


## Entry 15: 2 hours, 01.07.2026
Routed the thumb cluster so the entire right hand matrix is now finished, also routed all LEDs on the right side to the LED driver (which is actually a current sink lol). Rerouted a lot of the previous days' work to make it cleaner, after sleeping on it I realized that a lot of the routing could be redone in a much more elegant way.
TODO: Figure out power plane 3.3 and 5V separation and pours.
TODO: Fix trace and via width for power traces.

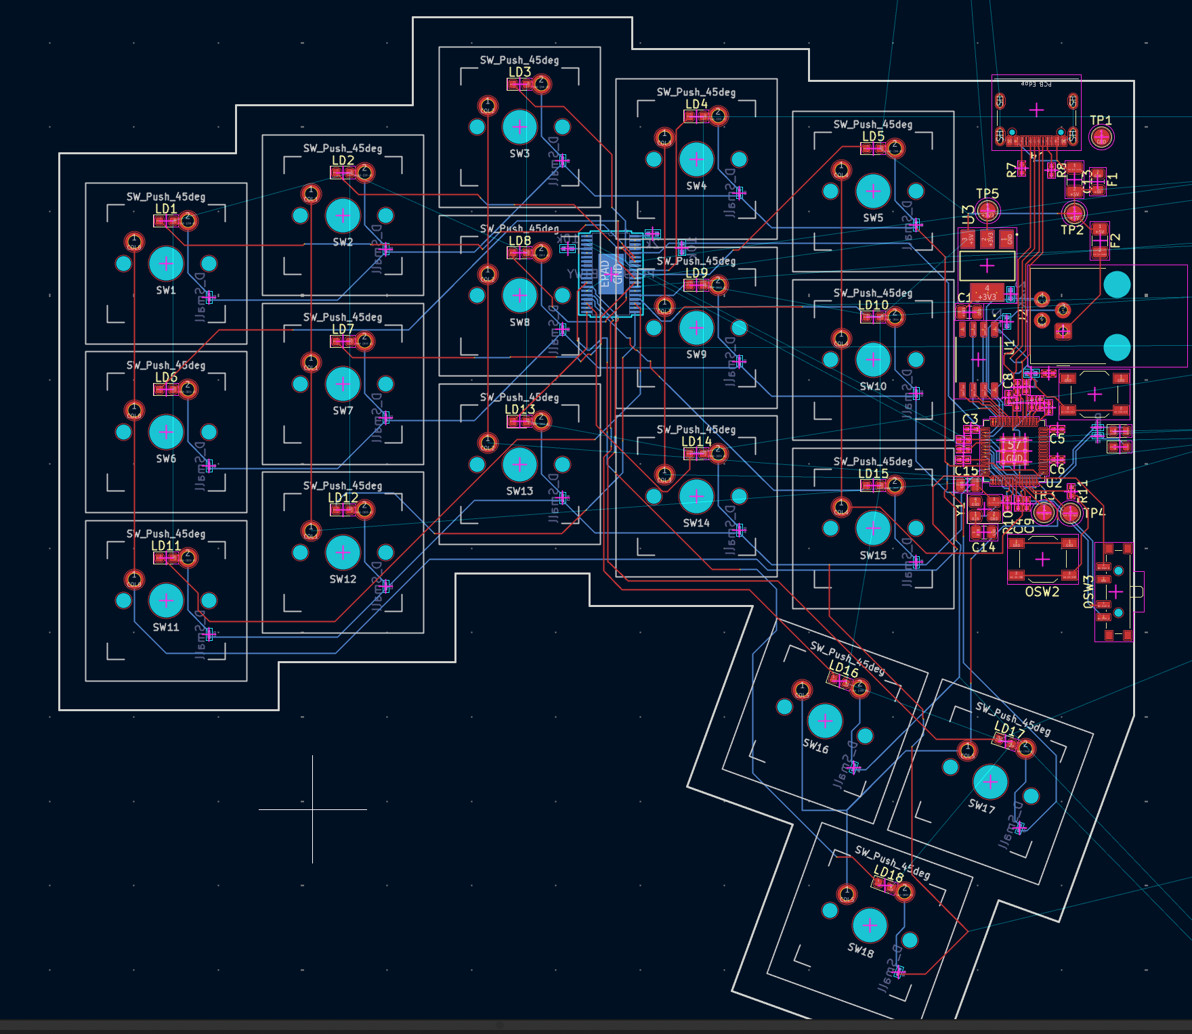
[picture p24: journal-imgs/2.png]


## Entry 16: 9 hours, 05.07.2026

(I did this work over the course of a couple of days from 01.07.2026 to 05.07.2026)

On the left side of the split: 
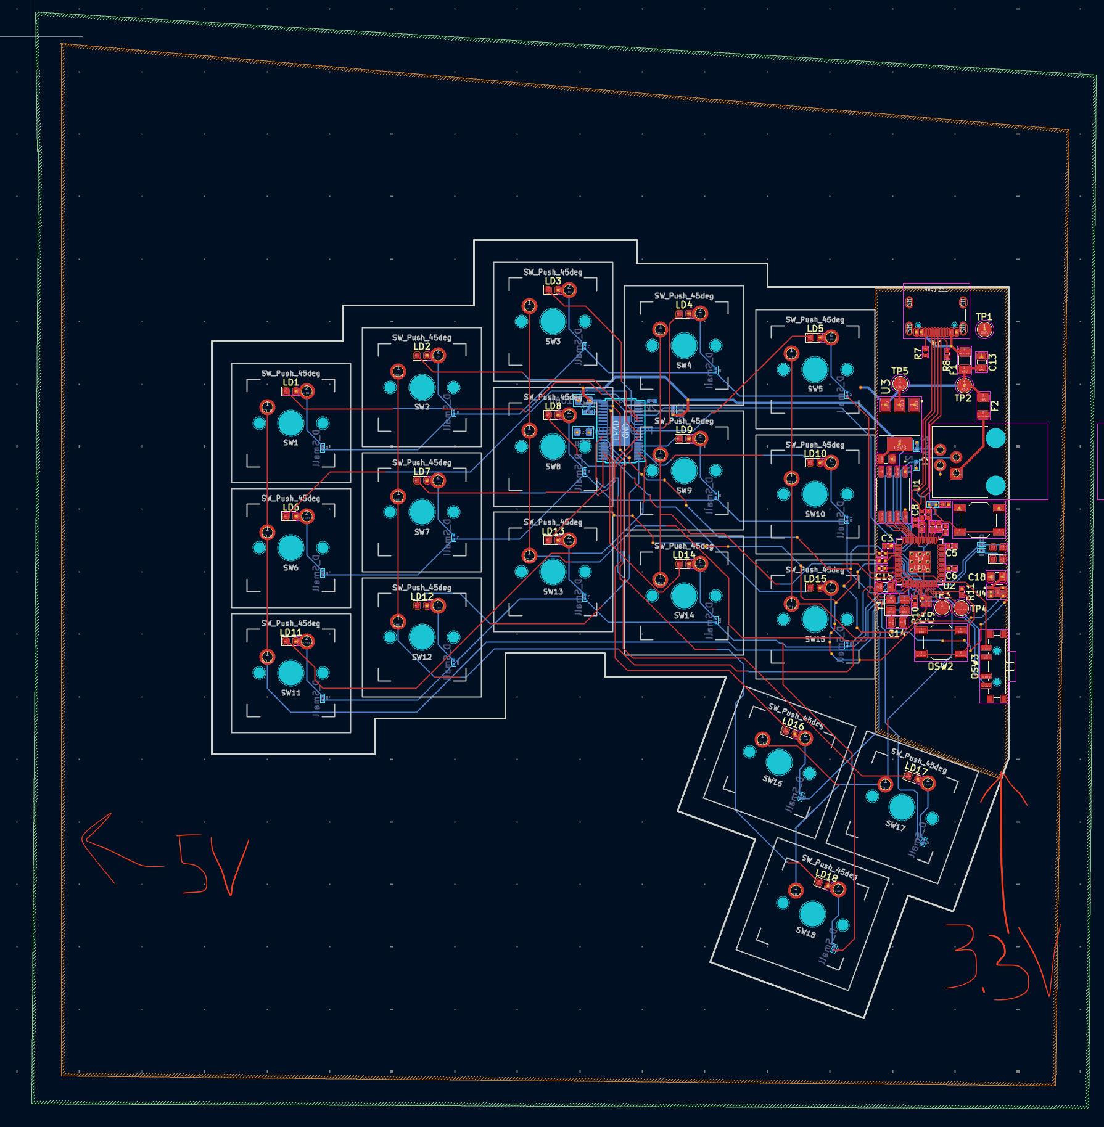
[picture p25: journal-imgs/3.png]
Seperated 3.3V and 5V copper pours on the same layer: 

Figured out how to use netclasses and set the 3.3V and 5V power traces to be 0.4mm wide and increased the via size for all traces (didn't retroactively apply them to all tho).

Routed the entire right side of the split: 
- MCP23017 (I2C IO expander communicating with the master side via I2C over RJ9 connector + wire)
- PCA9956 (LED driver to drive 3 status LEDs + 18 (1 per key) backlighting LEDs)
- NCP1117 (Voltage regulator, to power the 3.3V net, power comes in as 5V over RJ9)
- OPT3001 (a second I2C light sensor, enables automatic, brightness-driven backlight brightness adjustments)

Added the ground and split power plane pours from the left (master) side to the right side.

On the right side, since kbplacer assigned LED footprints from top to bottom, not from left to right, even though I had corrected the designtors to make them sequential from left to right, the majority of LED pads were referencing the wrong nets.

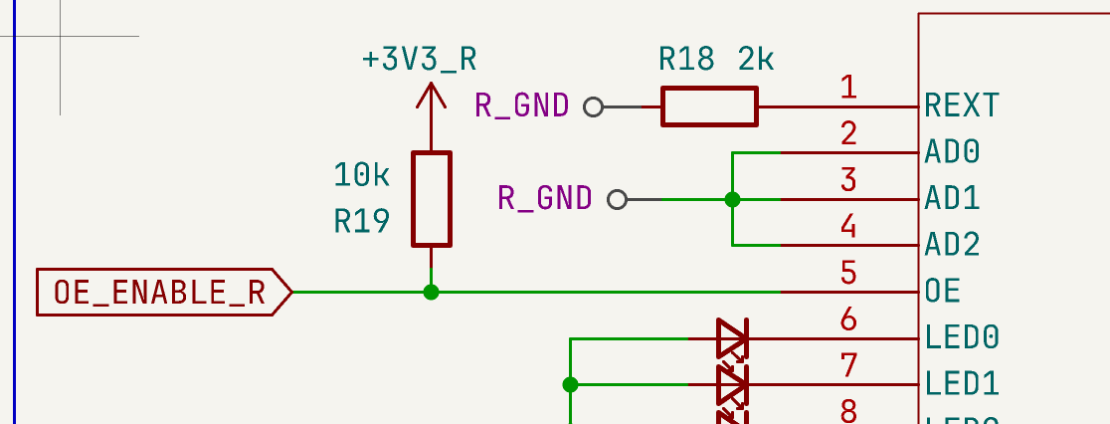
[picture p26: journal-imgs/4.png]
I spent a lot of time on fixing R_GND connections, as there was no net automatically generated and I had to manually find and reassign all ground connections (This was likely because i used a "Directive Label" in the schematic). Example of R_GND usage in the schematic: 

TODO: Assign JLC part numbers
TODO: Fix 300+ DRC errors and 200+ warnings

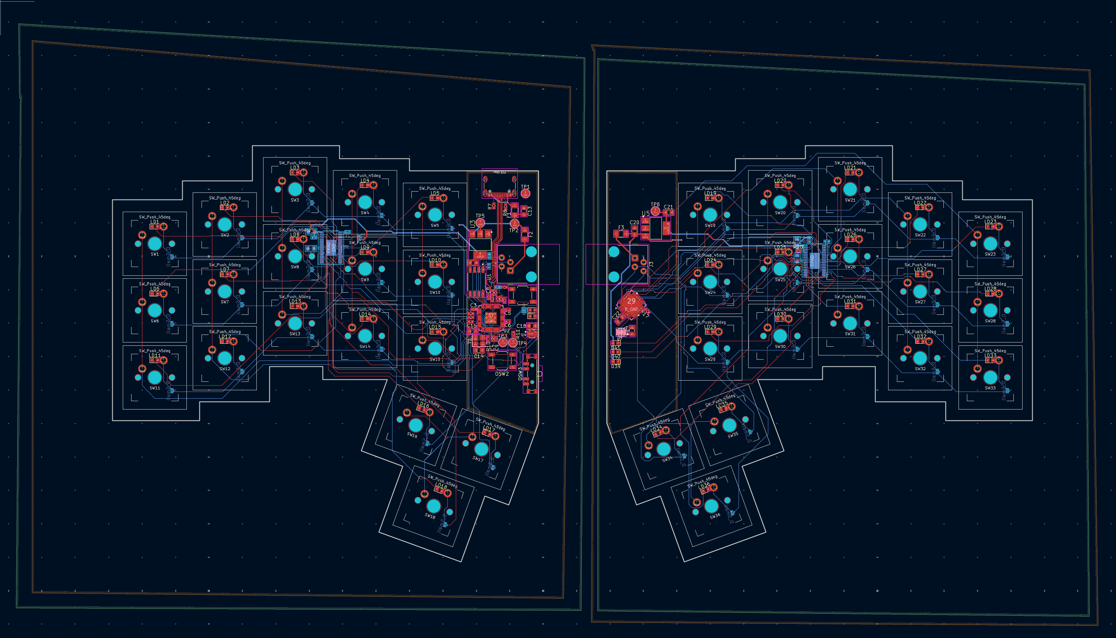
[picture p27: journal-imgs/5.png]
Entire PCB (finished, apart from the TODOs): 

## Entry 17: 1 hour, 05.07.2026

Fixed all DRC errors and most warnings. I discovered that the severity of violations can also be customized, and I set Silkscreen violations to ignore as I've heard the PCB fab will figure it out (JLC at least). I will probably fix them some time in the future, but if everything is correct, the board should be finished!
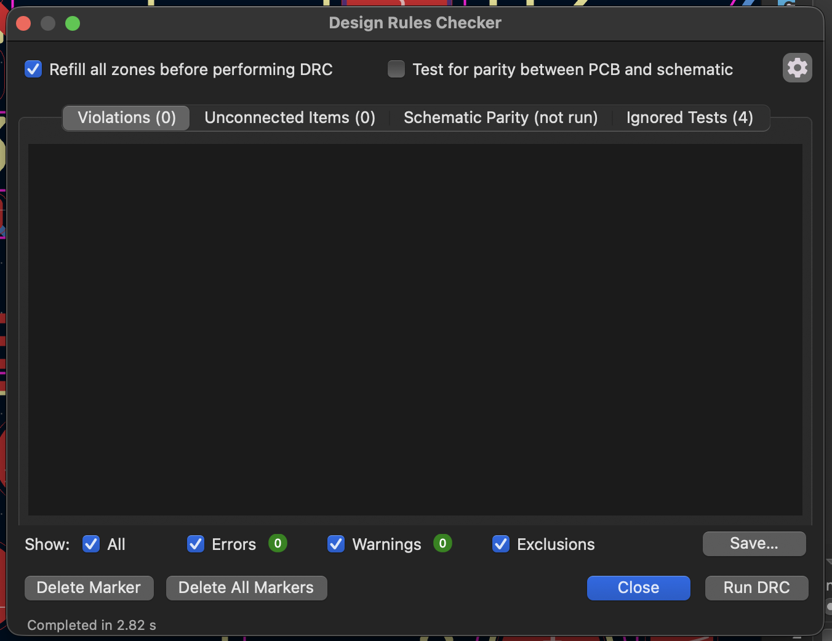
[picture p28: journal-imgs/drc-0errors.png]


TODO: Assign JLC part numbers!!
TODO: Add screw mounting holes!
TODO: BOM.csv!
TODO: Minimal encloure (just standoffs into a plate on bottom)

## Entry 18: 10 hours, 09.07.2026
Assigned all the LCSC numbers, had to redo it multiple times due to wrong packages and swapped out a few footprints due to missing LCSC products. 

Placed the PCA9956 LED drivers and all other footprints from the back to the front in order to use JLC's economic tier of the PCBA service. This took a lot of time as I had to reroute all 36 LEDs.

Added M2 screw holes, five per side at important locations, to screw the PCB into the enclosures' standoffs.

After I saw the JLC order totalling over 200€, I rotated one half of the split and moved it much closer to the other half, connecting the two with mousebites. This space saving brought the total cost down to around 125€.

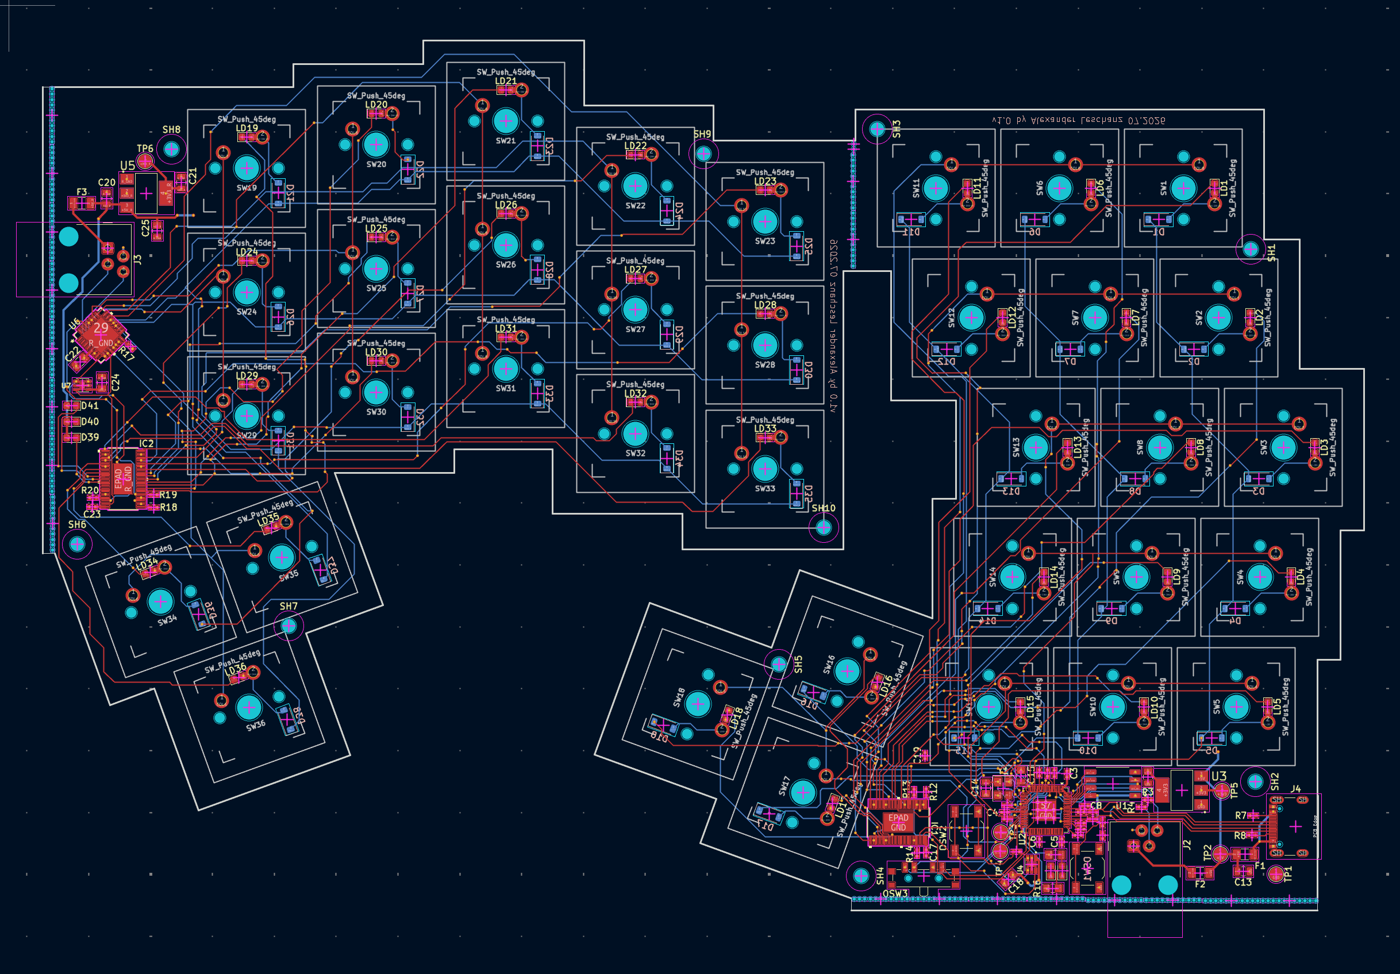
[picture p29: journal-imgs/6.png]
Compacted final PCB layout with LED drivers on the front surface and screw holes: 

## Entry 19: 2 hours, 10.07.2026
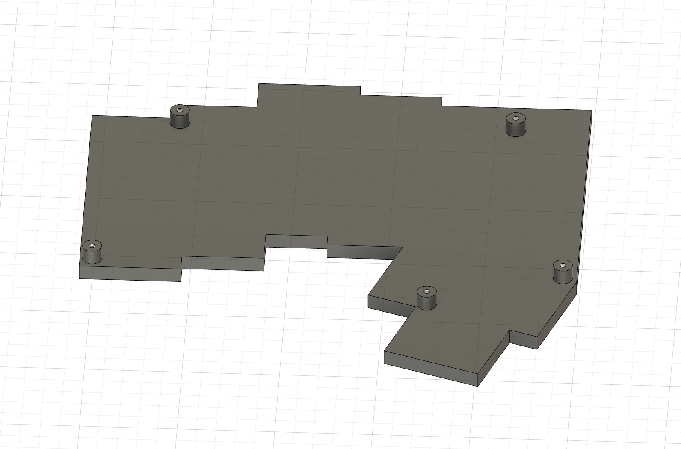
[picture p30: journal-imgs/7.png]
Designed a basic case with standoffs to mount the PCB on in Fusion. This pretty simple part took a long time because this is my first time using Fusion. Finished product: 
I will have it CNC'd out of aluminium by JLCCNC, which seems to be the most cost-effective option.

## Entry 20: 28.08.2026: 4 hours of build time
This is the first entry in a pretty long time, a lot has happened since the last entry! 

I ordered the PCB which ended up costing 206$ + about 50$ in customs/fees.
The PCBs arrived, and it worked perfectly, except - It didn't. The RP2040 booted up perfectly but as soon as I tried to flash a test firmware, the board (used as a storage device) ejected itself from Finder. 

After some continuity testing with a multimeter, I discovered that I had connected the QSPI CS (chip select) pin of the RP2040 (Pin 56) to the IOVDD pin (Pin 1, a 3,3V input pin powering the RP2040's GPIO pins) and the CS pin (Pin 1) of the WS25Q128 storage chip to the 3,3V net by connecting it to pin 8 of the same chip, which was tied to 3,3V.
This made the storage chip unusable as the chip select pin doesn't ever select or deselect the chip.
KiCad's ratsnet led me to believe I had to connect these two (by displaying "+3V3" on them), and I didn't double check with the datasheet one last time before ordering.

Due to me not having a hot air station at home, I went to a hackspace in Vienna ([Metalab](https://metalab.at/) in the first district, you should check it out!!) to try and fix the board.

First I desoldered the RP2040:


And broke the connection between pin 56 and pin 1 by scratching it up with a knife: 
As I've never used a hot air station before, I may have broken the RP2040 and/or W25Q128 storage chip by using too much heat for too long.
I don't have solder paste, flux or a stencil for the RP2040, and I am not confident that I am able to resolder it correctly.

While desoldering the storage chip, I unfortunately broke off one of its leads, so I'll have to find a replacement for it.

I also took some product photos while I was in the city:
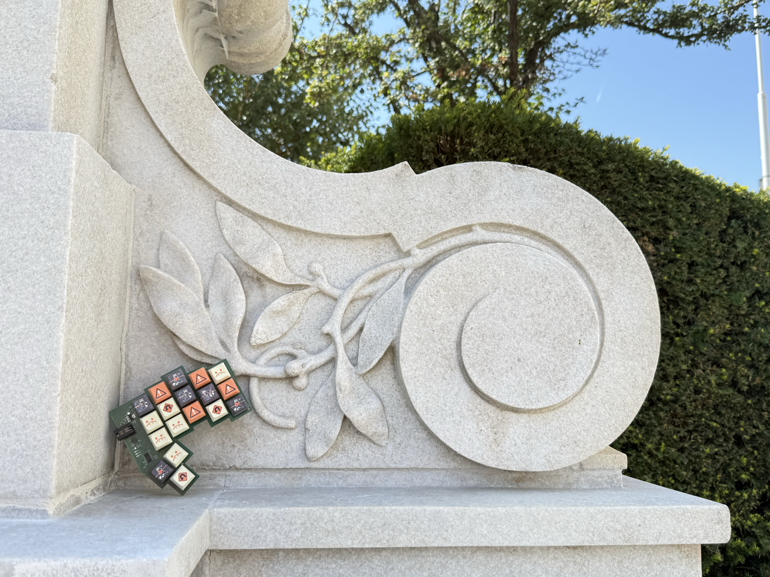
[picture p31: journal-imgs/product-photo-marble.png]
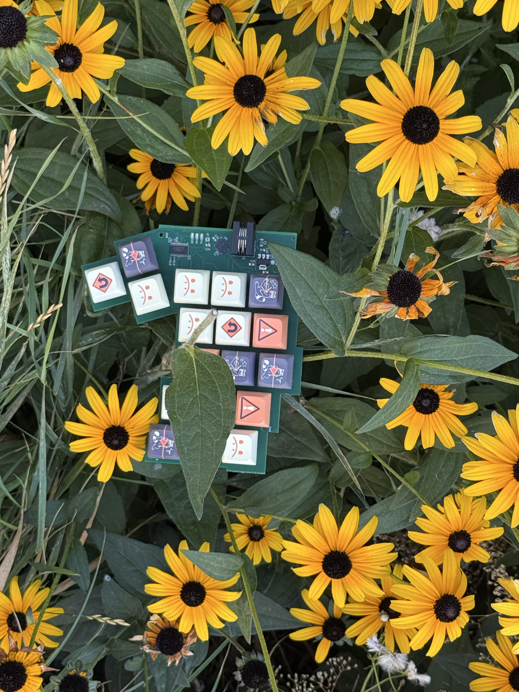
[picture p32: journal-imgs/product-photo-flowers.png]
| | |  |  |
|-|-|-|-|

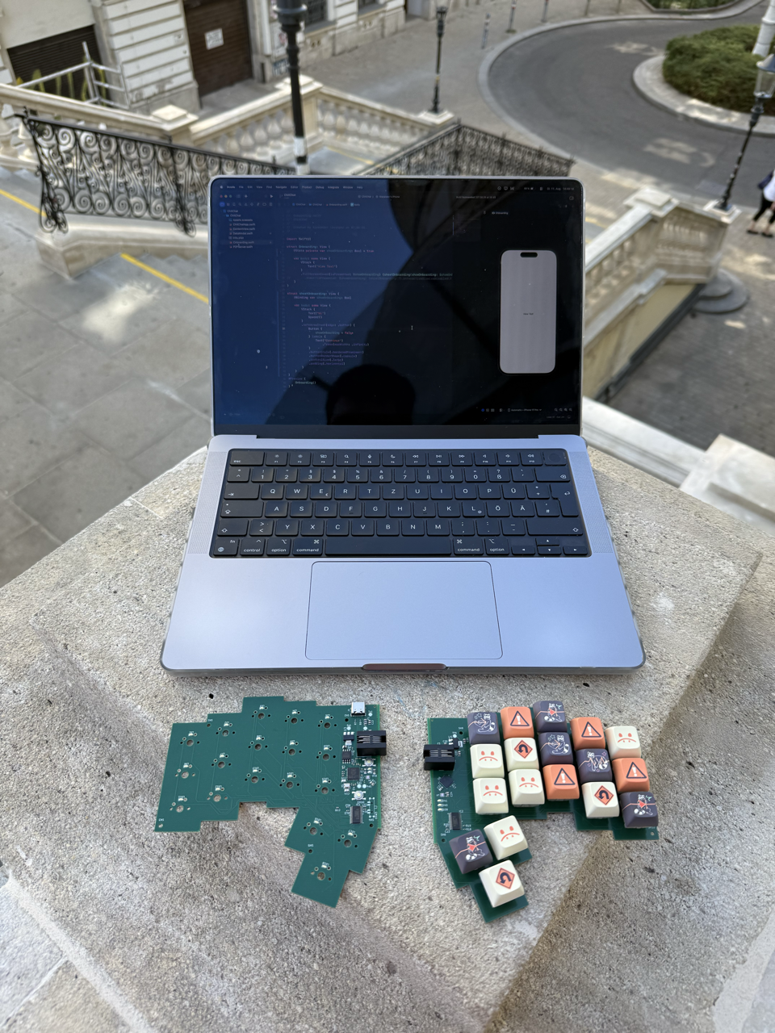
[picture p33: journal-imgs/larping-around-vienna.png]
Me larping around in Vienna with the non-functional keyboard: 

RUNNING TOTAL: 67h 20m (including the 40min lost by lapse)

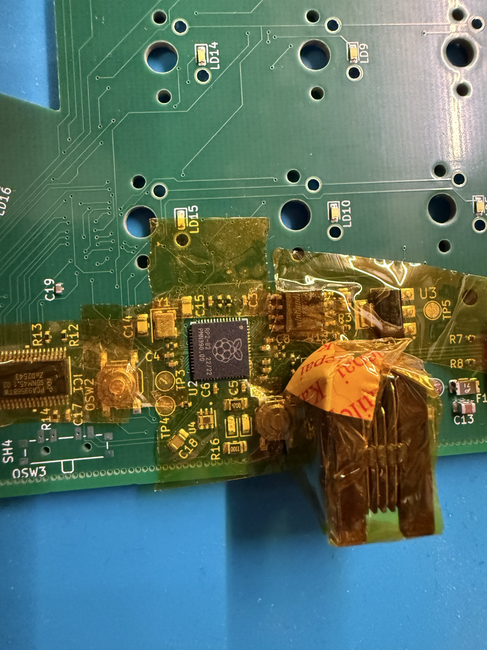
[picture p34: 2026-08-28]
journal-imgs/fixing-before-close.png

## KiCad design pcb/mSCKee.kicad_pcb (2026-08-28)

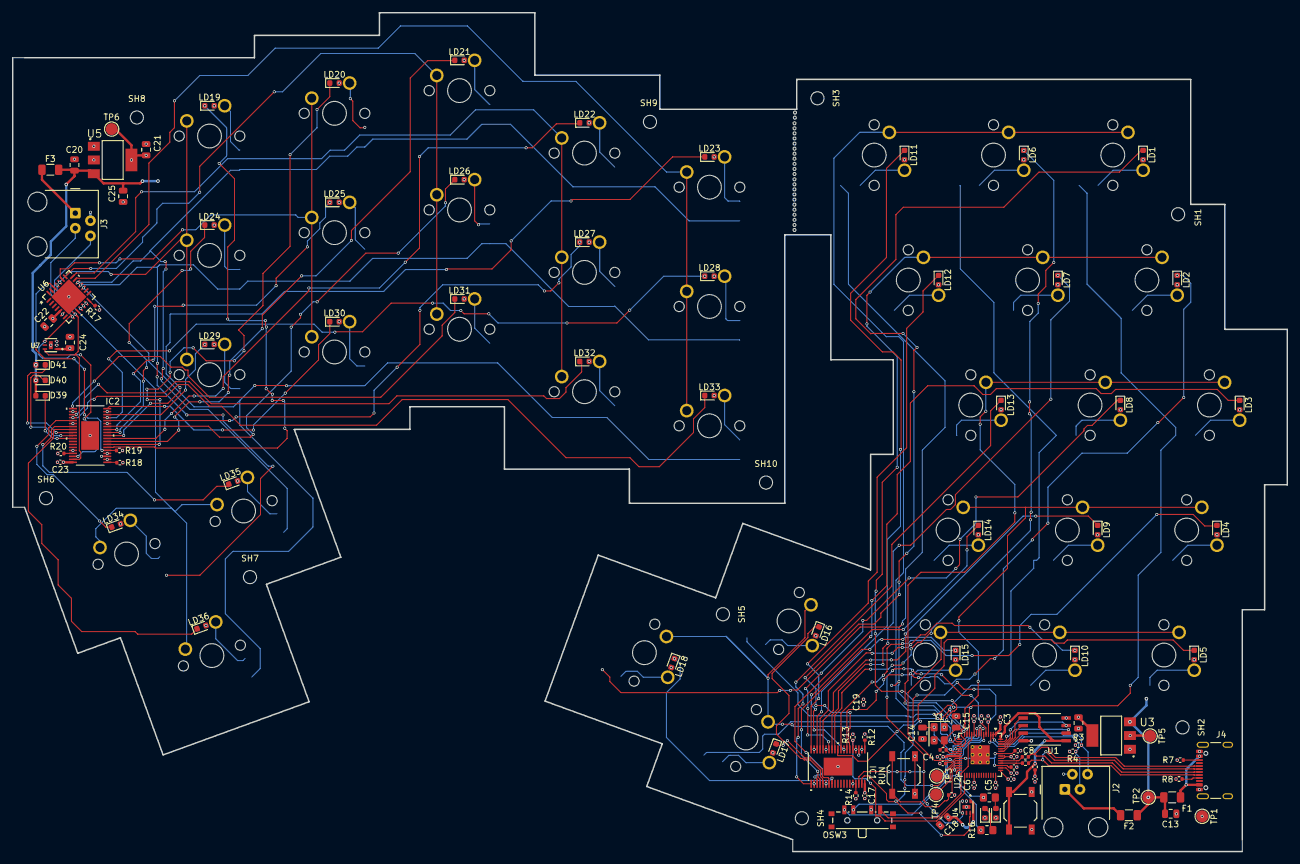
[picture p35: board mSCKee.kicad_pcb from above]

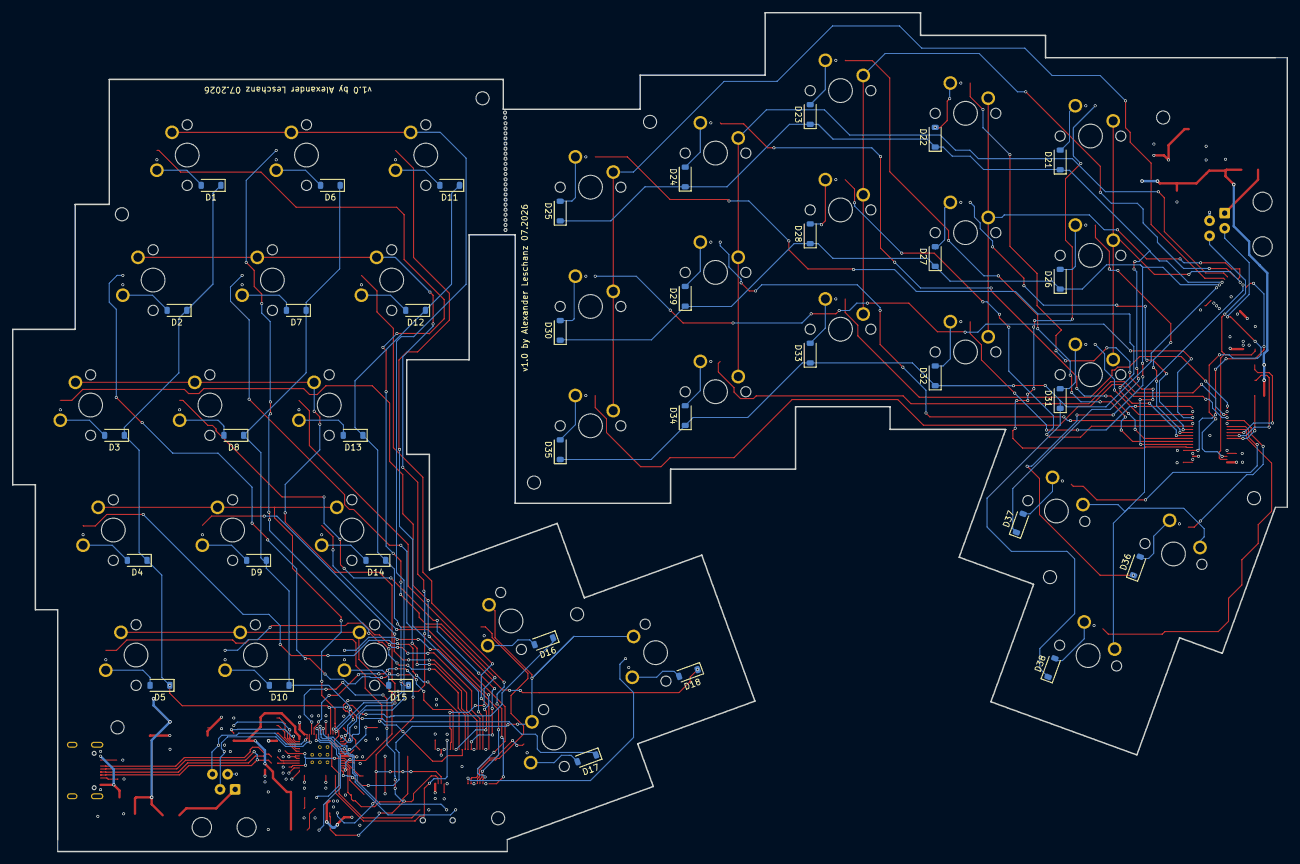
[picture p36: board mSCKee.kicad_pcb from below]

Board: 4 copper layers, 213.7 x 140.6 mm, 205 parts (36 on the bottom side), 141 nets.

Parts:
BL1, BL2: BreakLine_11h_D0.5mm_P0.85mm
BL3P, BL4P: (no value)
C1, C2, C3, C4, C5, C6, C7, C8, C9, C12, C17, C23: 100n; C_0402_1005Metric
C10, C11: 1u; C_0402_1005Metric
C13, C16, C20, C21, C25: 10u; C_0805_2012Metric
C14, C15: 15p; C_0805_2012Metric
C18, C22, C24: 100n; C_0805_2012Metric
C19: 10u; C_0402_1005Metric
D1, D2, D3, D4, D5, D6, D7, D8, D9, D10, D11, D12, D13, D14, D15, D16, D17, D18, D21, D22, D23, D24, D25, D26, D27, D28, D29, D30, D31, D32, D33, D34, D35, D36, D37, D38: D_Small; D_SOD-123
D19, D20: LED; LED_0603_1608Metric
D39, D40, D41: LED_Small; LED_0603_1608Metric
F1, F2, F3: Polyfuse_Small; Fuse_1206_3216Metric
IC1, IC2: PCA9956BTWY; HTSSOP38_4P4X9P7_NXP
J2, J3: 4P4C; RJ9_Evercom_5301-440xxx_Horizontal
J4: USB_C_Receptacle_USB2.0_16P; USB_C_Receptacle_GCT_USB4105-xx-A_16P_TopMnt_Horizontal
LD1, LD2, LD3, LD4, LD5, LD6, LD7, LD8, LD9, LD10, LD11, LD12, LD13, LD14, LD15, LD16, LD17, LD18, LD19, LD20, LD21, LD22, LD23, LD24, LD25, LD26, LD27, LD28, LD29, LD30, LD31, LD32, LD33, LD34, LD35, LD36: LED_Small; LED_0603_1608Metric
OSW1, OSW2: SW_Push; SW_SPST_TL3342
OSW3: SW_SP3T; SW_SP3T_PCM13
R1, R2: 27; R_0402_1005Metric
R3, R4: 2.2k; R_0402_1005Metric
R5, R6: 4.7k; R_0402_1005Metric
R7, R8: 5.1k; R_0402_1005Metric
R9, R10: 1k; R_0402_1005Metric
R11, R13, R14, R17, R19, R20: 10k; R_0402_1005Metric
R12, R18: 3k; R_0402_1005Metric
R15: 470; R_0805_2012Metric_Pad1.20x1.40mm_HandSolder
R16: 330; R_0805_2012Metric_Pad1.20x1.40mm_HandSolder
SH1, SH2, SH3, SH4, SH5, SH6, SH7, SH8, SH9, SH10: MountingHole_2.2mm_M2
SW1, SW2, SW3, SW4, SW5, SW6, SW7, SW8, SW9, SW10, SW11, SW12, SW13, SW14, SW15, SW16, SW17, SW18, SW19, SW20, SW21, SW22, SW23, SW24, SW25, SW26, SW27, SW28, SW29, SW30, SW31, SW32, SW33, SW34, SW35, SW36: SW_Push_45deg; MX-Solderable-1U
TP1, TP2, TP3, TP4, TP5, TP6: TestPoint; TestPoint_Pad_D2.0mm
TV2, TV3, TV4, TV5, TV6, TV7, TV8, TV9: (no value)
U1: W25Q128JVSIQ; SOIC127P790X216-8N
U2: RP2040; QFN-56-1EP_7x7mm_P0.4mm_EP3.2x3.2mm
U3, U5: NCP1117LPST33T3G; SOT230P700X175-4N
U4, U7: OPT3001DNPR; SON65P200X200X65-7N
U6: MCP23017T-E/ML; QFN28_6x6MC_MCH
Y1: ABM8-272-T3; Crystal_SMD_3225-4Pin_3.2x2.5mm

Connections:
+3V3: C1.1, C2.1, C3.1, C4.1, C5.1, C6.1, C7.1, C10.1, C12.2, C16.1, C17.1, C18.1, IC1.3 (AD1), IC1.38 (VDD), R3.1, R4.1, R5.1, R6.1, R9.1, R11.1, R13.2, R14.1, TP5.1 (1_1), U1.8 (VCC), U2.1 (IOVDD), U2.10 (IOVDD), U2.22 (IOVDD), U2.33 (IOVDD), U2.42 (IOVDD), U2.43 (ADC_AVDD), U2.44 (VREG_IN), U2.48 (USB_VDD), U2.49 (IOVDD), U3.2 (OUTPUT), U3.4 (OUTPUT__1), U4.1 (VDD)
+3V3_R: C21.1, C22.2, C23.2, C24.1, IC2.3 (AD1), IC2.38 (VDD), R17.1, R19.2, R20.1, TP6.1 (1_1), U5.2 (OUTPUT), U5.4 (OUTPUT__1), U6.5 (VDD), U7.1 (VDD)
+5V: C13.1, C19.1, F1.2, F2.1, LD1.2 (A), LD2.2 (A), LD3.2 (A), LD4.2 (A), LD5.2 (A), LD6.2 (A), LD7.2 (A), LD8.2 (A), LD9.2 (A), LD10.2 (A), LD11.2 (A), LD12.2 (A), LD13.2 (A), LD14.2 (A), LD15.2 (A), LD16.2 (A), LD17.2 (A), LD18.2 (A), TP2.1 (1_1), U3.3 (INPUT)
+5V_R: C20.1, C25.1, D39.2 (A), D40.2 (A), D41.2 (A), F3.2, LD19.2 (A), LD20.2 (A), LD21.2 (A), LD22.2 (A), LD23.2 (A), LD24.2 (A), LD25.2 (A), LD26.2 (A), LD27.2 (A), LD28.2 (A), LD29.2 (A), LD30.2 (A), LD31.2 (A), LD32.2 (A), LD33.2 (A), LD34.2 (A), LD35.2 (A), LD36.2 (A), U5.3 (INPUT)
/master_side/QSPI_SCLK: U1.6 (CLK), U2.52 (QSPI_SCLK)
/master_side/QSPI_SD0: U1.5 (DI(IO0)), U2.53 (QSPI_SD0)
/master_side/QSPI_SD1: U1.2 (DO(IO1)), U2.55 (QSPI_SD1)
/master_side/QSPI_SD2: U1.3 (/WP(IO2)), U2.54 (QSPI_SD2)
/master_side/QSPI_SD3: U1.7 (/HOLD/RESET(IO3)), U2.51 (QSPI_SD3)
/master_side/USB_D+: J4.A6 (D+), J4.B6 (D+), R1.1
/master_side/USB_D-: J4.A7 (D-), J4.B7 (D-), R2.1
/master_side/XIN: C14.1, U2.20 (XIN), Y1.1
/master_side/XOUT: R10.1, U2.21 (XOUT)
BL_DIM_1: OSW3.1, U2.8 (GPIO6)
BL_DIM_2: OSW3.2, U2.9 (GPIO7)
BL_DIM_3: OSW3.4, U2.11 (GPIO8)
COL0: SW1.1, SW6.1, SW11.1, U2.15 (GPIO12)
COL1: SW2.1, SW7.1, SW12.1, U2.16 (GPIO13)
COL2: SW3.1, SW8.1, SW13.1, U2.17 (GPIO14)
COL3: SW4.1, SW9.1, SW14.1, U2.18 (GPIO15)
COL4: SW5.1, SW10.1, SW15.1, U2.27 (GPIO16)
COL5: SW16.1, SW17.1, SW18.1, U2.28 (GPIO17)
COL6: SW34.1, SW35.1, SW36.1, U6.25 (GPB0)
COL7: SW19.1, SW24.1, SW29.1, U6.24 (GPA7)
COL8: SW20.1, SW25.1, SW30.1, U6.23 (GPA6)
COL9: SW21.1, SW26.1, SW31.1, U6.22 (GPA5)
COL10: SW22.1, SW27.1, SW32.1, U6.21 (GPA4)
COL11: SW23.1, SW28.1, SW33.1, U6.20 (GPA3)
GND: C1.2, C2.2, C3.2, C4.2, C5.2, C6.2, C7.2, C8.2, C9.2, C10.2, C11.2, C12.1, C13.2, C14.2, C15.2, C16.2, C17.2, C18.2, C19.2, D19.1 (K), D20.1 (K), IC1.2 (AD0), IC1.4 (AD2), IC1.14 (VSS), IC1.18 (VSS), IC1.21 (VSS), IC1.25 (VSS), IC1.34 (VSS), IC1.EPAD, J2.2, J4.A1 (GND), J4.A12 (GND), J4.B1 (GND), J4.B12 (GND), OSW1.1, OSW2.1, OSW3.3, R7.1, R8.1, R12.1, TP1.1 (1_1), TV2.101 (GND), TV3.102 (GND), TV4.103 (GND), TV5.104 (GND), TV6.105 (GND), TV7.106 (GND), TV8.107 (GND), TV9.108 (GND), U1.4 (GND), U2.19 (TESTEN), U2.57 (GND), U3.1 (GND), U4.2 (ADDR), U4.3 (GND), U4.7 (EXP), Y1.2, Y1.4
I2C_CLK: IC1.36 (SCL), R6.2, U2.5 (GPIO3), U4.4 (SCL)
I2C_CLK_R: J2.3, R4.2, U2.3 (GPIO1)
I2C_D: IC1.37 (SDA), R5.2, U2.4 (GPIO2), U4.6 (SDA)
I2C_D_R: J2.4, R3.2, U2.2 (GPIO0)
unnamed: C15.1, R10.2, Y1.3
unnamed: D3.2 (A), SW3.2
unnamed: D23.2 (A), SW21.2
unnamed: D4.2 (A), SW4.2
unnamed: D22.2 (A), SW20.2
unnamed: D5.2 (A), SW5.2
unnamed: D21.2 (A), SW19.2
unnamed: D2.2 (A), SW2.2
unnamed: D24.2 (A), SW22.2
unnamed: D1.2 (A), SW1.2
unnamed: D25.2 (A), SW23.2
unnamed: D8.2 (A), SW8.2
unnamed: D28.2 (A), SW26.2
unnamed: D9.2 (A), SW9.2
unnamed: D27.2 (A), SW25.2
unnamed: D10.2 (A), SW10.2
unnamed: D26.2 (A), SW24.2
unnamed: D7.2 (A), SW7.2
unnamed: D29.2 (A), SW27.2
unnamed: D19.2 (A), R15.2
unnamed: D20.2 (A), R16.2
unnamed: D6.2 (A), SW6.2
unnamed: D30.2 (A), SW28.2
unnamed: D13.2 (A), SW13.2
unnamed: D33.2 (A), SW31.2
unnamed: D14.2 (A), SW14.2
unnamed: D32.2 (A), SW30.2
unnamed: D15.2 (A), SW15.2
unnamed: D31.2 (A), SW29.2
unnamed: D12.2 (A), SW12.2
unnamed: D34.2 (A), SW32.2
unnamed: D11.2 (A), SW11.2
unnamed: D35.2 (A), SW33.2
unnamed: D16.2 (A), SW16.2
unnamed: D37.2 (A), SW35.2
unnamed: D17.2 (A), SW17.2
unnamed: D36.2 (A), SW34.2
unnamed: D18.2 (A), SW18.2
unnamed: D38.2 (A), SW36.2
unnamed: D39.1 (K), IC2.30 (LED20)
unnamed: D40.1 (K), IC2.29 (LED19)
unnamed: D41.1 (K), IC2.28 (LED18)
unnamed: F1.1, J4.A4 (VBUS), J4.A9 (VBUS), J4.B4 (VBUS), J4.B9 (VBUS)
unnamed: F2.2, J2.1
unnamed: F3.1, J3.1
unnamed: IC1.6 (LED0), LD1.1 (K)
unnamed: IC1.7 (LED1), LD2.1 (K)
unnamed: IC1.8 (LED2), LD3.1 (K)
unnamed: IC1.9 (LED3), LD4.1 (K)
unnamed: IC1.10 (LED4), LD5.1 (K)
unnamed: IC1.11 (LED5), LD6.1 (K)
unnamed: IC1.12 (LED6), LD7.1 (K)
unnamed: IC1.13 (LED7), LD8.1 (K)
unnamed: IC1.15 (LED8), LD9.1 (K)
unnamed: IC1.16 (LED9), LD10.1 (K)
unnamed: IC1.17 (LED10), LD11.1 (K)
unnamed: IC1.19 (LED11), LD12.1 (K)
unnamed: IC1.20 (LED12), LD13.1 (K)
unnamed: IC1.22 (LED13), LD14.1 (K)
unnamed: IC1.23 (LED14), LD15.1 (K)
unnamed: IC1.24 (LED15), LD16.1 (K)
unnamed: IC1.26 (LED16), LD17.1 (K)
unnamed: IC1.27 (LED17), LD18.1 (K)
unnamed: IC1.35 (RESET), R14.2
unnamed: IC1.1 (REXT), R12.2
unnamed: IC2.6 (LED0), LD19.1 (K)
unnamed: IC2.7 (LED1), LD20.1 (K)
unnamed: IC2.8 (LED2), LD21.1 (K)
unnamed: IC2.9 (LED3), LD22.1 (K)
unnamed: IC2.10 (LED4), LD23.1 (K)
unnamed: IC2.11 (LED5), LD24.1 (K)
unnamed: IC2.12 (LED6), LD25.1 (K)
unnamed: IC2.13 (LED7), LD26.1 (K)
unnamed: IC2.15 (LED8), LD27.1 (K)
unnamed: IC2.16 (LED9), LD28.1 (K)
unnamed: IC2.17 (LED10), LD29.1 (K)
unnamed: IC2.19 (LED11), LD30.1 (K)
unnamed: IC2.20 (LED12), LD31.1 (K)
unnamed: IC2.22 (LED13), LD32.1 (K)
unnamed: IC2.23 (LED14), LD33.1 (K)
unnamed: IC2.24 (LED15), LD34.1 (K)
unnamed: IC2.26 (LED16), LD35.1 (K)
unnamed: IC2.27 (LED17), LD36.1 (K)
unnamed: IC2.35 (RESET), R20.2
unnamed: IC2.1 (REXT), R18.2
unnamed: J4.A5 (CC1), R8.2
unnamed: J4.B5 (CC2), R7.2
unnamed: OSW2.2, R11.2, U2.26 (RUN)
unnamed: TP3.1 (1_1), U2.24 (SWCLK)
unnamed: TP4.1 (1_1), U2.25 (SWD)
unnamed: R2.2, U2.46 (USB_DM)
unnamed: R1.2, U2.47 (USB_DP)
unnamed: C8.1, C9.1, C11.1, U2.23 (DVDD), U2.45 (VREG_VOUT), U2.50 (DVDD)
unnamed: R17.2, U6.14 (*RESET)
OE_ENABLE: IC1.5 (OE), R13.1, U2.29 (GPIO18)
OE_ENABLE_R: IC2.5 (OE), R19.1, U6.26 (GPB1)
QSPI_SS: OSW1.2, R9.2, U1.1 (/CS), U2.56 (QSPI_SS)
ROW0: D1.1 (K), D2.1 (K), D3.1 (K), D4.1 (K), D5.1 (K), D16.1 (K), U2.12 (GPIO9)
ROW0_R: D21.1 (K), D22.1 (K), D23.1 (K), D24.1 (K), D25.1 (K), D37.1 (K), U6.19 (GPA2)
ROW1: D6.1 (K), D7.1 (K), D8.1 (K), D9.1 (K), D10.1 (K), D17.1 (K), U2.13 (GPIO10)
ROW1_R: D26.1 (K), D27.1 (K), D28.1 (K), D29.1 (K), D30.1 (K), D36.1 (K), U6.18 (GPA1)
ROW2: D11.1 (K), D12.1 (K), D13.1 (K), D14.1 (K), D15.1 (K), D18.1 (K), U2.14 (GPIO11)
ROW2_R: D31.1 (K), D32.1 (K), D33.1 (K), D34.1 (K), D35.1 (K), D38.1 (K), U6.17 (GPA0)
R_GND: C20.2, C21.2, C22.1, C23.1, C24.2, C25.2, IC2.2 (AD0), IC2.4 (AD2), IC2.14 (VSS), IC2.18 (VSS), IC2.21 (VSS), IC2.25 (VSS), IC2.34 (VSS), IC2.EPAD, J3.2, R18.1, U5.1 (GND), U6.6 (VSS), U6.11 (A0), U6.12 (A1), U6.13 (A2), U6.29 (HTAB), U7.2 (ADDR), U7.3 (GND), U7.7 (EXP)
STATUS1: R15.1, U2.6 (GPIO4)
STATUS2: R16.1, U2.7 (GPIO5)
S_M_CLOCK: IC2.36 (SCL), J3.3, U6.8 (SCL), U7.4 (SCL)
S_M_DATA: IC2.37 (SDA), J3.4, U6.9 (SDA), U7.6 (SDA)

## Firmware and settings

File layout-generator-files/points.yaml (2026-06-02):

matrix_pinky_bottom:
  x: 50
  'y': -100
  r: 0
  meta:
    stagger: 0
    spread: 20.955000000000002
    splay: 0
    origin:
      - 0
      - 0
    orient: 0
    shift:
      - 0
      - 0
    rotate: 0
    adjust: {}
    width: 18
    height: 18
    padding: 20.0025
    autobind: 10
    skip: false
    asym: both
    colrow: pinky_bottom
    name: matrix_pinky_bottom
    column_net: COL0
    row_net: ROW2
    mirror:
      row_net: ROW2R
    zone: &ref_1
      columns:
        pinky: &ref_0
          key:
            column_net: COL0
            splay: 0
            spread: 1.1U
          rows: {}
          name: pinky
        ring: &ref_2
          key:
            column_net: COL1
            stagger: 0.30U
            splay: 0
            spread: 1.1U
          rows: {}
          name: ring
        middle: &ref_3
          key:
            column_net: COL2
            stagger: 0.55U
            splay: 0
            spread: 1.1U
          rows: {}
          name: middle
        index: &ref_4
          key:
            column_net: COL3
            stagger: '-0.20U'
            splay: 0
            spread: 1.1U
          rows: {}
          name: index
        index_1: &ref_5
          key:
            column_net: COL4
            stagger: '-0.20U'
            splay: 0
            spread: 1.1U
          rows: {}
          name: index_1
      rows:
        bottom:
          row_net: ROW2
          mirror:
            row_net: ROW2R
          padding: 1.05U
        home:
          row_net: ROW1
          mirror:
            row_net: ROW1R
          padding: 1.05U
        number:
          row_net: ROW0
          mirror:
            row_net: ROW0R
          padding: 1.05U
      name: matrix
    col: *ref_0
    row: bottom
    mirrored: false
    bind:
      - 10
      - 0
      - 0
      - 0
matrix_pinky_home:
  x: 50
  'y': -79.9975
  r: 0
  meta:
    stagger: 0
    spread: 20.955000000000002
    splay: 0
    origin:
      - 0
      - 0
    orient: 0
    shift:
      - 0
      - 0
    rotate: 0
    adjust: {}
    width: 18
    height: 18
    padding: 20.0025
    autobind: 10
    skip: false
    asym: both
    colrow: pinky_home
    name: matrix_pinky_home
    column_net: COL0
    row_net: ROW1
    mirror:
      row_net: ROW1R
    zone: *ref_1
    col: *ref_0
    row: home
    mirrored: false
    bind:
      - 10
      - 10
      - 10
      - 0
matrix_pinky_number:
  x: 50
  'y': -59.995000000000005
  r: 0
  meta:
    stagger: 0
    spread: 20.955000000000002
    splay: 0
    origin:
      - 0
      - 0
    orient: 0
    shift:
      - 0
      - 0
    rotate: 0
    adjust: {}
    width: 18
    height: 18
    padding: 20.0025
    autobind: 10
    skip: false
    asym: both
    colrow: pinky_number
    name: matrix_pinky_number
    column_net: COL0
    row_net: ROW0
    mirror:
      row_net: ROW0R
    zone: *ref_1
    col: *ref_0
    row: number
    mirrored: false
    bind:
      - 0
      - 10
      - 10
      - 0
matrix_ring_bottom:
  x: 70.955
  'y': -94.285
  r: 0
  meta:
    stagger: 5.715
    spread: 20.955000000000002
    splay: 0
    origin:
      - 0
      - 0
    orient: 0
    shift:
      - 0
      - 0
    rotate: 0
    adjust: {}
    width: 18
    height: 18
    padding: 20.0025
    autobind: 10
    skip: false
    asym: both
    colrow: ring_bottom
    name: matrix_ring_bottom
    column_net: COL1
    row_net: ROW2
    mirror:
      row_net: ROW2R
    zone: *ref_1
    col: *ref_2
    row: bottom
    mirrored: false
    bind:
      - 10
      - 0
      - 0
      - 10
matrix_ring_home:
  x: 70.955
  'y': -74.2825
  r: 0
  meta:
    stagger: 5.715
    spread: 20.955000000000002
    splay: 0
    origin:
      - 0
      - 0
    orient: 0
    shift:
      - 0
      - 0
    rotate: 0
    adjust: {}
    width: 18
    height: 18
    padding: 20.0025
    autobind: 10
    skip: false
    asym: both
    colrow: ring_home
    name: matrix_ring_home
    column_net: COL1
    row_net: ROW1
    mirror:
      row_net: ROW1R
    zone: *ref_1
    col: *ref_2
    row: home
    mirrored: false
    bind:
      - 10
      - 10
      - 10
      - 10
matrix_ring_number:
  x: 70.955
  'y': -54.28
  r: 0
  meta:
    stagger: 5.715
    spread: 20.955000000000002
    splay: 0
    origin:
      - 0
      - 0
    orient: 0
    shift:
      - 0
      - 0
    rotate: 0
    adjust: {}
    width: 18
    height: 18
    padding: 20.0025
    autobind: 10
    skip: false
    asym: both
    colrow: ring_number
    name: matrix_ring_number
    column_net: COL1
    row_net: ROW0
    mirror:
      row_net: ROW0R
    zone: *ref_1
    col: *ref_2
    row: number
    mirrored: false
    bind:
      - 0
      - 10
      - 10
      - 0
matrix_middle_bottom:
  x: 91.91
  'y': -83.8075
  r: 0
  meta:
    stagger: 10.477500000000001
    spread: 20.955000000000002
    splay: 0
    origin:
      - 0
      - 0
    orient: 0
    shift:
      - 0
      - 0
    rotate: 0
    adjust: {}
    width: 18
    height: 18
    padding: 20.0025
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

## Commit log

2025-11-02 feat: init KiCad project & add RP2040
    [mSCKee.kicad_pcb, mSCKee.kicad_sch]
2025-11-13 chore: Reinit and readd RP2040 minimal circuit
    [mSCKee.kicad_sch]
2025-11-13 feat(schematic): Connect crystal and flash chip to RP2040
    [mSCKee.kicad_pcb, mSCKee.kicad_sch]
2025-11-14 feat(schematic): Wire up USB-C receptacle
    [mSCKee.kicad_sch]
2025-11-17 feat(schematic): Add GPIO connection labels and an LED to one
    [mSCKee.kicad_sch]
2025-12-19 misc: Add keep QSPI conn short
    [mSCKee.kicad_sch]
2026-01-29 feat: Add TRRS receptacle and split sheets into master & slave side
    [mSCKee.kicad_sch, master_side.kicad_sch, slave_side.kicad_sch]
2026-01-31 Add TRRS connector, rotary encoder, ambient light sensor
    [mSCKee.kicad_sch, master_side.kicad_sch]
2026-02-01 Restructure file & folder layout
    [OPT3001DNPR.step, PCA9956BTWY.step, mSCKee.kicad_pcb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]
2026-02-02 update readme
    Added a section for current progress with an image.
2026-02-23 feat: Add more components, add finalized outline
    [54-00174.step, NCP1117LPST33T3G.step, OPT3001DNPR.step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]
2026-03-01 feat: Add both sides of outline in CAD
    [master_side.kicad_sch, outline_and_keys.dxf]
2026-03-25 feat: Further develop right side
    [54-00174.step, PCA9555DB_118.step, mSCKee.kicad_pcb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]
2026-03-25 fix: left/right nets separation
    [HTSSOP38_4P4X9P7_NXP.step, PCA9956BTWY.step, mSCKee.kicad_pcb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]
2026-03-26 feat: Replace PCA9555 with MCP23017
    [PCA9555DB_118.step, QFN28_6x6MC_MCH.step, mSCKee.kicad_pcb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]
2026-03-27 fix: I2C pullups on both buses
    [master_side.kicad_sch, slave_side.kicad_sch]
2026-03-27 fix: Proper MX LED footprint
    [mSCKee.kicad_pcb, master_side.kicad_sch, slave_side.kicad_sch]
2026-03-27 fix: revert to proper switch footprint without SMD LED
    [mSCKee.kicad_pcb, master_side.kicad_sch, slave_side.kicad_sch]
2026-03-28 fix: OE pin PCA9956B control on startup
    [master_side.kicad_sch, slave_side.kicad_sch]
2026-03-30 fix: PCA9956 OE pin and RESET pin and improve LED power delivery
    [master_side.kicad_sch, slave_side.kicad_sch]
2026-03-31 fix: Diode & switch numbering for kbplacer
    [master_side.kicad_sch, slave_side.kicad_sch]
2026-03-31 fix: Update points to be both sides of keyboard
    Diode numbers don't match though
    [mSCKee.kicad_pcb]
2026-03-31 feat: Better global label names
    [master_side.kicad_sch]
2026-03-31 fix: Proper USB-C receptacle symbol
    [mSCKee.kicad_pcb, master_side.kicad_sch, slave_side.kicad_sch]
2026-06-02 fix: Fix thumb cluster key splay & Correctly align keys to outline in PCB layout
    [mSCKee.kicad_pcb, mSCKee.kicad_sch, master_side.kicad_sch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]
2026-06-02 chore(for future reference): Properly lay out keys, keep components unrouted
    [mSCKee.kicad_pcb, outline_and_keys.dxf]
2026-06-04 fix(broken): Reroute USB
    TODO:
    - Fix 0402 imperial and metric confusion
    - Fix DRC errors (are holes of claws of USB-C and ethernet big enough to manufacture?)
    - Proper decoupling cap distribution between pins
    - Manage the +1.1V and +3.3V situation (maybe create +1.1V net)
    [mSCKee.kicad_pcb, master_side.kicad_sch]
2026-06-05 feat: Improve layout & route crystal and flash
    [mSCKee.kicad_pcb, master_side.kicad_sch]
2026-06-25 feat: Add NC flags to both side schematics
    [mSCKee.kicad_pcb, master_side.kicad_sch, slave_side.kicad_sch]
2026-06-25 feat: Add I2C left side pullups, move status LED resistors to backside
    [mSCKee.kicad_pcb]
2026-06-27 feat: Route switches amongst themselves & Remove weirdly behaving netclass sizes
    TODO: route LD's and figure out how to connect them all to the driver (put driver IC on back side of board?)
    [mSCKee.kicad_pcb]
2026-06-30 chore: Restructure Journal (import from fallout) for outpost
    [mSCKee.kicad_pcb, master_side.kicad_sch]
2026-06-30 feat: Route master-side LEDs to driver
    TODO route matrix on thumb cluster master side
    [mSCKee.kicad_pcb]
2026-07-01 feat: Route right thumb cluster matrix, route matrix to MCU on master side
    [mSCKee.kicad_pcb]
2026-07-02 chore: Update Journal
    [mSCKee.kicad_pcb]
2026-07-03 fix: Make matrix wiring cleaner (left), fix LED pins from +5V to +5V_R (right)
    [mSCKee.kicad_pcb]
2026-07-03 feat: Split left side power plane into +5V two thirds and +3V3 one third
    [mSCKee.kicad_pcb]
2026-07-03 feat: Add 3.3V and 5V netclasses and pattern matching to nets
2026-07-03 fix: Create seperate nets for rows on right side, assign right side LED pads to proper IC2(n) nets
    [mSCKee.kicad_pcb]
2026-07-03 feat: bigger via size
    [mSCKee.kicad_pcb]
2026-07-04 fix: Change MCP23017 ROW pins to _R ones
    [mSCKee.kicad_pcb]
2026-07-04 fix(left side): Made power traces wider, simplified W25Q128 storage interrupt switch routing with vias to 3.3V
    [mSCKee.kicad_pcb, master_side.kicad_sch]
2026-07-04 feat: left: Wire up OPT3001 light sensor, wire up rest of I2C bus to PCA9956 LED driver, right side: Wire up ROWs to MCP23017, fix: change right thumb cluster from COL7 to COL6
    [mSCKee.kicad_pcb]
2026-07-04 feat(right side): Add same copper pours as left side, route NCP1117 and other power components
    [mSCKee.kicad_pcb]
2026-07-05 feat: Route entire right half: matrix, LEDs, OPT3001, I2C
    Should all be finished, maybe I made some mistakes.
    [mSCKee.kicad_pcb]
2026-07-05 chore: Update journal, save DRC report
    Kicad auto made a bunch of changes to the PCB I didn't do but aight
    [mSCKee.kicad_pcb]
2026-07-05 fix: Set all vias to netclass size, fix about half of DRC violations
    [mSCKee.kicad_pcb]
2026-07-05 fix: DRC violations, 0 errors, about 70 silkscreen warnings remain
    [mSCKee.kicad_pcb]
2026-07-05 feat(left side): Add 5 mounting holes
    [mSCKee.kicad_pcb]
2026-07-05 feat: Set grid origin to exactly center between the halves, add mounting holes to both sides and align them
    [mSCKee.kicad_pcb]
2026-07-05 fix: Replace all 0201 doides with bigger SOD-123 ones and rewire accordingly
    [mSCKee.kicad_pcb]
2026-07-08 feat: Add screw mount holes, add more JLC part numbers, fix DRC violations, remove all components at least 1mm from the edge of the board, add Cherry switch 3D model to ai03 footprint
    [kiswitch-SW_Cherry_MX_PCB.stp, mSCKee.kicad_pcb, master_side.kicad_sch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]
2026-07-09 fix: Size all footprints on the back side 0805 for hand soldering
    [mSCKee.kicad_pcb, master_side.kicad_sch, slave_side.kicad_sch]
2026-07-09 feat(right side): Put PCA9956 onto front of PCB
    [mSCKee.kicad_pcb]
2026-07-09 feat(actually right side): Put everything on the back to the front of PCB
    Last commit was for the LEFT side, but commit message was wrong
    [mSCKee.kicad_pcb]
2026-07-09 fix: R footprint used on C
    [mSCKee.kicad_pcb]
2026-07-09 feat: Add rectangle around entire rotated PCB for panelization, add mousebite footprints to project
    [mSCKee.kicad_pcb]
2026-07-09 fix: Mousebite hole spacing
    [mSCKee.kicad_pcb]
2026-07-09 feat: Design minimal enclosure for keyboard
    [minimal Case.f3z]
2026-07-10 chore: Update README
    [BOM-mSCKee.csv, mSCKee.kicad_pcb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]
2026-07-10 chore: Add seperate BOM.csv and final case STEP
    [BOM.csv, minimal Case.step]
2026-07-10 chore: Add schematic screenshots to README
2026-07-10 chore: Add some unused assets for archival purposes
    [BOM-mSCKee.csv, minimal Case final.step, minimal Case.f3z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]
2026-07-24 chore: Clean up dir structure
    [outline_and_keys.dxf]
2026-08-19 fix: QSPI wiring & remove edge mousebites
    Edge mousebites probably will never be snapped off anyways, since they are extremely (<3mm) close to SMD components that might crack or otherwise fail when that sort of pressure is applied around them.
    [BOM-mSCKee.csv, mSCKee.kicad_pcb]
2026-08-19 chore: Unified folder naming scheme
    [BOM-mSCKee.csv, minimal Case final.step, minimal Case.f3z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]
2026-08-20 chore: Fix up README with IRL product pictures, bring BOM up to date
    [BOM.csv]
2026-08-28 fix: Create QSPI_SS net to fix PCB routing error & chore: Fix journal image paths
    [mSCKee.kicad_pcb]
2026-08-28 chore(journal): Add build journal entry
    [mSCKee.kicad_pcb]
